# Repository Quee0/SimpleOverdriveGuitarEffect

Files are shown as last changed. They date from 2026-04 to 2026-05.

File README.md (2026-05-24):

# Ignis Overdrive Effect :fire: :guitar:

<p align="left">
  
  
  
  
</p>

<p align="center">
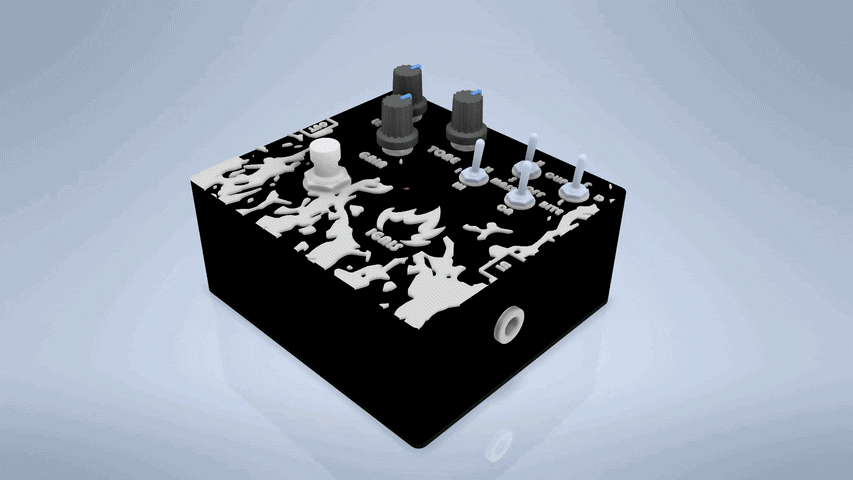
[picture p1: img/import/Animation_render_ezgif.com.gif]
  
</p>

---

## 1. Project overview

### 1.1 General Description

This project presents the complete design and mathematical analysis of a versatile, fully analog overdrive guitar pedal built around an operational amplifier.
At its core, the main amplification block delivers a massive voltage gain (up to 1000x), paired with a flexible multi segmented tonal shaping section. 

> [!NOTE]
>This includes:
>* Hardware pre-amp bass switch to modify the low-end structure before clipping,
>* Low-pass pre-amp filter integrated into the feedback loop, it actively works with gain and can be switched on and off,
>* Customizable clipping: fast-switching silicon diodes and LEDs, hard and soft clipping.
>* Final refinements through a classic passive Tone control (lowpass filter),
>* Master volume stage with DC-blocking (static high pass filter), 

The end result is a highly customizable overdrive capable of spanning from a transparent, mid-focused crunch to a thick, saturated lead tone, demonstrating a practical understanding of circuit design and mathematical theory usage.

### 1.2 Sound Demonstrations

<details>
<summary><b>Soft Clipping, LED Diodes, Mass I, Bite ON, Mid Gain, Low Tone</b></summary>

https://github.com/user-attachments/assets/1be89b33-93ce-4a43-86b3-0c42de0525c9

</details>

<details>
<summary><b>Soft Clipping, LED Diodes, Mass I, Bite ON, Mid Gain, High Tone</b></summary>

https://github.com/user-attachments/assets/2ba2562c-e011-4fdd-8f06-044c0ea2faf1

</details>

<details>
<summary><b>Soft Clipping, LED Diodes, Mass II, Bite ON, Mid Gain, Mid Tone</b></summary>

https://github.com/user-attachments/assets/6c816d3a-e20a-423a-b53f-dbef71fd2bd0

</details>

<details>
<summary><b>Soft Clipping, Fast-switching Diodes, Mass I, Bite ON, Mid Gain, Mid Tone</b></summary>

https://github.com/user-attachments/assets/7a0f3d32-2f00-4b13-9497-afda9a19c826

</details>

<details>
<summary><b>Soft Clipping, Fast-switching Diodes, Mass I, Bite ON, Mid Gain, Mid Tone</b></summary>

https://github.com/user-attachments/assets/31108739-4f4a-404e-89c9-3ae1a5144b9c

</details>

### 1.3 User Guide

* **Footswitch** - `Enable / disable` guitar effect,
* **Level:** Master output volume control.
* **Gain:** Adjusts the voltage amplification of the primary op-amp stage. Turn clockwise to increase the amount of overdrive and saturation.
* **Tone** - Passive high-frequency roll-off. Turn clockwise for a brighter, sharper tone, or counter-clockwise for a darker, warmer sound.
* **Clip** - `Hard / Soft` Clipping mode toggle. *Note: Different clipping modes inherently yield different overall volume and compression levels. You will likely need to compensate with the Level knob.*
* **D** - `Fast-switching / None / LED` choose cliping diodes,
* **Mass** - `II / I / III` choose how massive you want the tone to be, how much to amplify the bass.
* **Bite** - `Off / On` Engages the feedback-loop smoothing capacitor (100pF). Turn it ON to roll off harsh high-end fizz and soften the overall clipping behavior.

---

## 2. Circuit
### 2.1 Schematic Diagram

<p align="center">
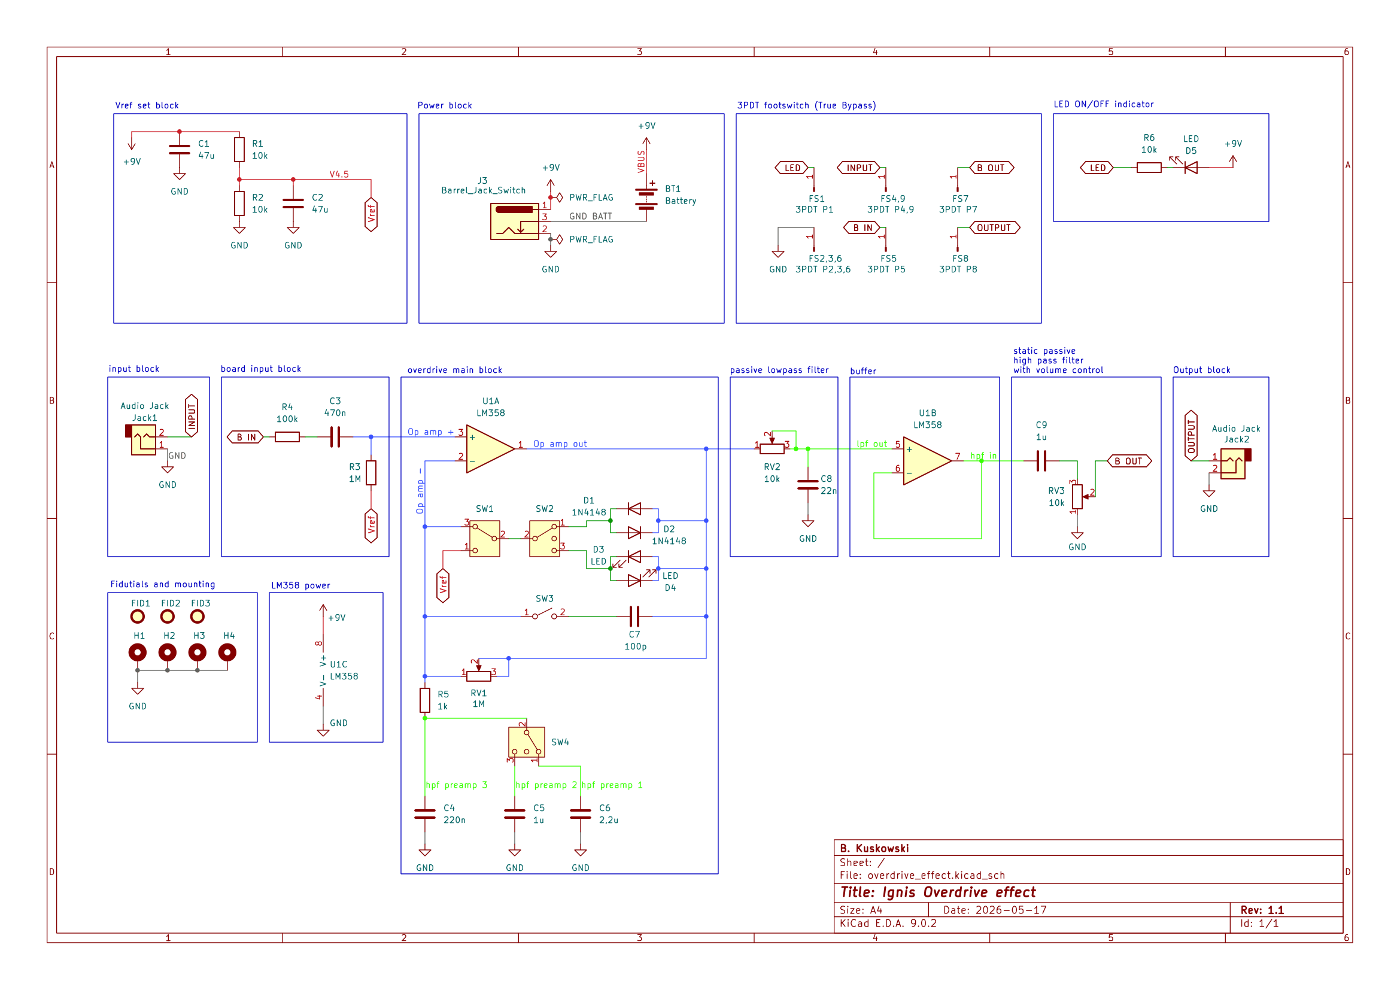
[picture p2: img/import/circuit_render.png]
  
</p>

**Block Diagram Explanation**
* **$V_{ref}$ set block** - steps down the 9V supply to create a 4.5V reference voltage, it allows to add DC part to an AC signal (center between 0V-9V power supply). Capacitors filter out power supply noise and stabilize this reference voltage.
* **Power block** - DC barrel jack integrated with a hardware battery disconnect mechanism. When an external power supply is plugged in, the battery circuit is physically broken to prevent unwanted discharging.
* **3PDT footswitch (True Bypass)** - Footswitch wiring schematic ensuring 100% mechanical true bypass. When the pedal is disengaged, the guitar signal routes directly to the output without passing through any electronic components, preserving maximum tone integrity. It also integrates LED indicators connection to ground when enabled. 
* **LED ON/OFF indicator** - it visually indicates when pedal is enabled.
* **input block and output block** - standard 6.3mm audio jack receiving/sending the instrument signal.
* **board input block** - Coupling capacitor with $V_{ref}$ resistance acts like differenting circuit and blocks DC voltage. Additionally this capacitor loads up to $V_{ref}$ 4.5V voltage that adds DC part to a signal.
* **overdrive main block** - the core of the effect, based on the LM358 operational amplifier. It handles signal amplification based on feedback loop impedances and features a versatile clipping section, offering a choice between fast-switching diodes and LEDs. It also includes tonal modifications: a switchable LPF in the feedback loop (SW3) to smooth out high-end fizz, and a pre-gain HPF (SW4) to control the low-end "mass" entering the clipping stage.
* **passive lowpass filter** - the classic Tone control section.
* **buffer** - effectively separates signal proccesing blocks from influencing one another.
* **static passive high pass filter with volume control** - output coupling capacitor blocks the internal $V_{ref}$ DC part, outputting a pure AC audio signal centered at 0V. Potentiometer acts as a voltage divider providing precise Master Volume control.
* **Fiducials and mounting** - purely mechanical parts to mount and produce PCB.
* **LM358 power** - LM358 powering diagram.

> [!NOTE]
> Upon later revision there are 2 possible further impovements:
> * While setting $V_{ref}$ use buffor to further stabilize reference potential point.
> * Add protective resistance to output of an op amp in main overdrive block.

### 2.2 PCB Layout

<p align="center">
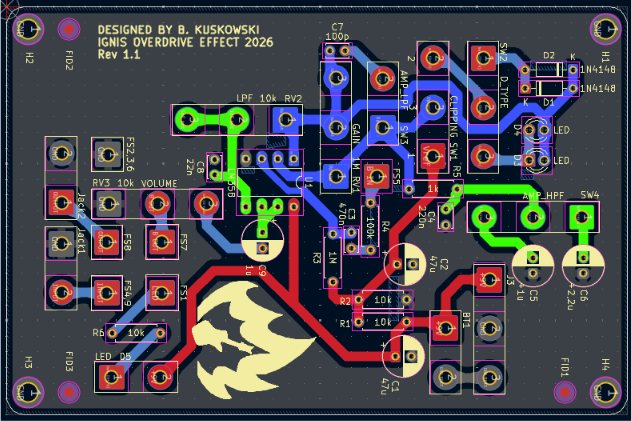
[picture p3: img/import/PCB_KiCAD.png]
  
</p>

<p align="center">
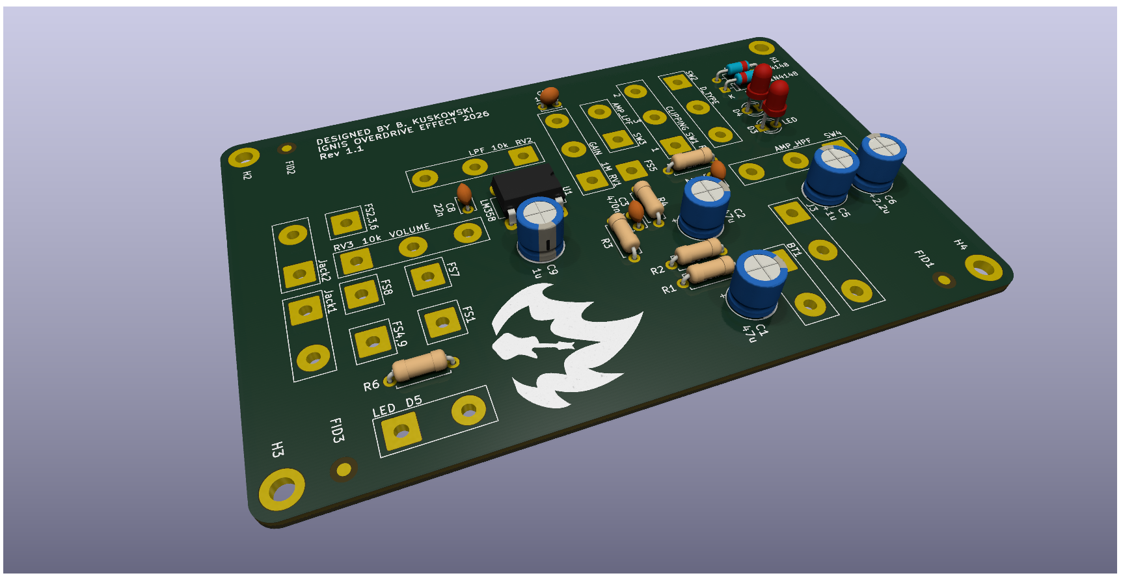
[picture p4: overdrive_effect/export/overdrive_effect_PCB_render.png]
  
</p>

<p align="center">
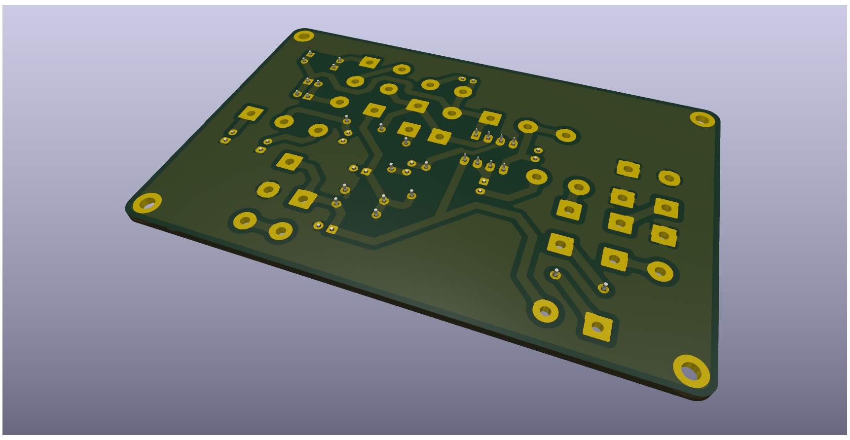
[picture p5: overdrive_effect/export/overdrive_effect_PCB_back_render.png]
  
</p>

PCB Layout Features.
Designed for maximum audio integrity, mechanical reliability, and DIY accessibility:
* **Low Noise (Solid Ground Plane)**: A continuous copper pour acts as an EMI shield, drastically reducing noise.
* **DIY & Fab-Friendly**: Intentionally routed as a single-sided board with wide traces and generous clearances. This makes it perfect for both home DIY etching (using thermotransfer) and professional, automated manufacturing.
* **Easy wiring**: Silkscreen layer was carefully described to assure smooth assembly.
* **Appropriate wire holes**: Apertures are wide enough for diverse wire usage.

<p align="center">
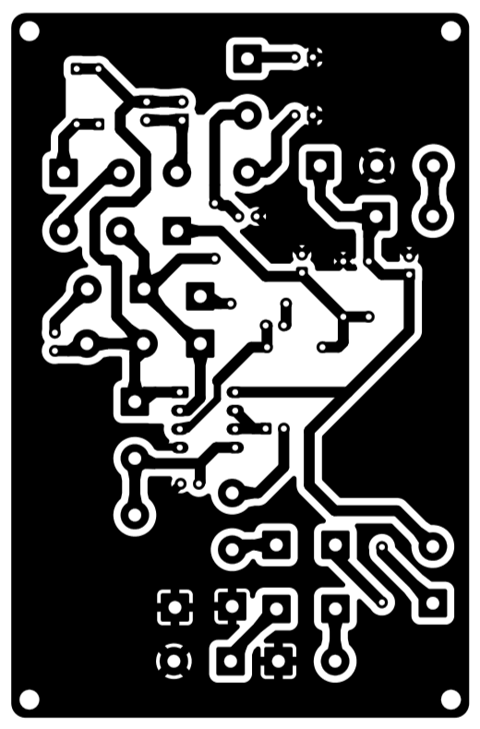
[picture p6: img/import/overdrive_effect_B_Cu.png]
  
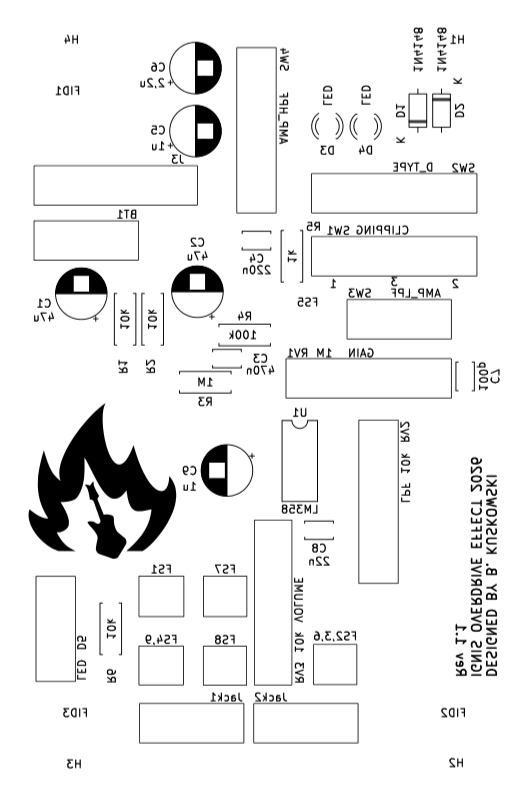
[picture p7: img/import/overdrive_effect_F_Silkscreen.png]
  
</p>

<p align="center">
PNGs of files ready to thermotransfer (pdfs in img\import)
</p>

---

## 3. Circuit analysis math derivation
<details>
<summary><b> Expand for further details </b></summary>

### 3.1 Derivation of cutoff frequency of coupling/decoupling capacitor

In this derivation we consider loaded decoupling capacitor which makes lowpass filter (integrating circuit).
The last derived equation in 3.1 is identical for coupling capacitor working with resistance (differentiating circuit), but it is different on laplace's s-domain, and in fourier analysis (phase and magnitude plots).

#### Voltage divider equation:

$$U_{out}=U_{in} \cdot \frac{Z_L}{Z_L+Z_R}$$

$$U_{out}=U_{in} \cdot \frac{\frac{Z_C Z_{Ro}}{Z_C+Z_{Ro}}}{\frac{Z_C Z_{Ro}}{Z_C+Z_{Ro}}+Z_R} = U_{in} \cdot \frac{Z_C Z_{Ro}}{Z_C Z_{Ro}+Z_C Z_{R}+Z_RZ_{Ro}}$$

#### Laplace's s-domain impedances derivation
Definition of Laplace's transform:

$$F(s) = L[f(t)] = \int_{0}^{\infty} f(t) e^{-st} \, dt \Rightarrow L\left[\frac{d^nf(t)}{dt^n}\right] = s^nF(s)$$

considering no initial conditions.

Impedance of resistance $Z_R$: 

$$U=I\cdot R$$
<!-- $$\mathcal{L}\{U\}=\mathcal{L}\{I\cdot R\}$$-->

$$L[U]=R\cdot L[I]$$

$$Z_R(s)=\frac{U(s)}{I(s)}=R$$

Impedance of capacitance $Z_C$:

$$I=C\cdot \frac{dU}{dt}$$

$$L[I]=C\cdot L[U']$$

$$I(s)=C\cdot sU(s)$$

$$Z_C(s)=\frac{U(s)}{I(s)}=\frac{1}{sC}$$

#### Substituting s-domain impedances to voltage divider equation:

$$G(s)=\frac{U_{out}}{U_{in}}=\frac{\frac{R_o}{sC}} {\frac{R_o}{sC}+\frac{R}{sC}+RR_o}=\frac{R_o}{R_o+R+sCRR_o}$$

$$G(s)=\frac{(\frac{R_o}{R_o+R})}{1+s(\frac{CRR_o}{R_o+R})}$$

Then:

**$$\boxed{G(s)=\frac{K}{1+sT}},\qquad   \boxed{K=\frac{R_o}{R_o+R}},\qquad   \boxed{T=\frac{CRR_o}{R_o+R}}$$**

---

#### Amplitude characteristic - Fourier analysis
Complex s-plane argument definition: $s = \sigma+j\omega$. To get amplitude characteristic we need to analyse holomorphic Fourier transform function. To achieve that we need to get rid of real part of s-plane (constant component $e^\sigma$).

$$G(j\omega)=\frac{K}{1+j\omega T}\cdot\frac{1-j\omega T}{1-j\omega T}=\frac{K-j\omega KT}{1+\omega^2 T^2}$$

$$G(j\omega)=\left[\frac{K}{1+\omega^2 T^2}\right] + j\left[\frac{-\omega KT}{1+\omega^2 T^2}\right]$$

<!-- ![](img\desmos_decoupling_Fourier.svg)(https://www.desmos.com/calculator/vwyactze44) -->
$P(\omega)\left[Q(\omega)\right]$ characteristics:
<p align="center">
  Podpis alternatywny
</p>
<p align="center">
    (https://www.desmos.com/calculator/vwyactze44)
</p>
To derive amplitude-frequency function we must analyse mod.

$$|G(j\omega)|=\sqrt{\frac{K^2}{(1+\omega^2 T^2)^2}+\frac{\omega^2 K^2 T^2}{(1+\omega^2 T^2)^2}}=\frac{K}{\sqrt{1+\omega^2 T^2}}$$

Finding -3dB frequency will be done based on magnitude.

$$A=20\cdot \log\left(\frac{K}{\sqrt{1+\omega^2 T^2}}\right)$$

Cutoff condition:

$$A(\omega_{-3dB})=A(0)-3$$

$$20\cdot \log\left(\frac{K}{\sqrt{1+\omega^2 T^2}}\right)=20\cdot \log\left(\frac{K}{\sqrt{1+0^2 T^2}}\right)-3$$

$$10\left[\log\left(\frac{K^2}{(1+\omega^2 T^2)}\right)-\log\left(K^2\right)\right]=-3$$

$$\log\left(\frac{1}{(1+\omega^2 T^2)}\right)=-0,3$$

$$\frac{1}{(1+4\pi^2f^2 T^2)}=10^{-0,3}$$

$$10^{-0,3}+10^{-0,3}4\pi^2f^2 T^2=1$$

$$f=\sqrt{\frac{\frac{10^{-0,3}}{1-10^{-0,3}}}{4\pi^2T^2}} \approx \frac{1}{2\pi T}$$

Substitute T:

$$f=\frac{R_o+R}{2\pi CRR_o}=\frac{R}{2\pi CRR_o}+\frac{R_o}{2\pi CRR_o}$$

**$$\boxed{f=\frac{1}{2\pi RC}+\frac{1}{2\pi R_oC}}$$**

---

### 3.2 Derivation of voltage divider resistance values

We consider loaded symetric voltage divider

#### Impedance

$$R_{eq1}=\frac{RR_o}{R+R_o}$$

$$\lim_{R_o \to \infty} R_{eq1}= \lim_{R_o \to \infty}\frac{R}{\frac{R}{R_o}+1}=R$$

$$R_{eq}=2\cdot R$$

#### Flowing current loss

$$I=\frac{V_{cc}}{R_{eq}}=\frac{V_{cc}}{2R}$$

#### Thevenin's resistance

$$R_{TH}=\frac{RR}{R+R}=\frac{R}{2} \Rightarrow R = 2\cdot R_{TH}$$

#### Current loss vs Thevenin's resistance

Substituting both equations:

**$$\boxed {I(R_{TH})=\frac{V_{cc}}{4\cdot R_{TH}}}$$**

Ideal voltage source should have $R_{TH} \to 0$, to be as stable as possible. Ideal current loss should be $I \to 0$. Graphing this function allow to pick optimal resistance values.

$I(R_{TH})$  with $V_{cc}=9V$ characteristics:
<p align="center">
  Podpis alternatywny
</p>
<p align="center">
    (https://www.desmos.com/calculator/zl9quwhx7r)
</p>

---

### 3.3 Derivation of pullup resistor value

Considering methodology of choosing pullup resistors, low potential on signal line should not draw much current.
On the other hand, operational amplifier has its bias current which will be drawn no matter what. It limits upper value of resistance, voltage drop on this resistor should not affect effect.

In project LM358 was used, so its bias current is around $45 nA = 45\cdot 10^{-9} A$

$$U = I\cdot R$$

$$R = \frac{U_{loss}}{45\cdot 10^{-9}}$$

Characteristics:
<p align="center">
  Podpis alternatywny
</p>
<p align="center">
    (https://www.desmos.com/calculator/fuyu1ywsum)
</p>

---

### 3.4 Operational amplifiers

Op amps has very high input impedance ($Z_{in} \to \infty$) and very low output impedance ($Z_{out} \to 0$).
They can be analysed using 2 rules:
1. Op amps try to sustain same potential on both of its inputs,
2. Op amps bias current is negligible small (often $I \to 0$).

---

Using 2 rules, non-inverting amp can be modeled with:

$$U_{in} = U_{+} = U_{-} = Z_1 \cdot I$$

$$U_{out} = U_{Z_1} + U_{Z_2} = I\cdot Z_1 + I\cdot Z_2 \Rightarrow I = \frac{U_{out}}{Z_1 + Z_2}$$

$$G(s) = \frac{Z_2 (s)}{Z_1(s)} + 1$$

In this effect we are enabling user to regulate $Z_2$ (diode type, potentiometer and capacitor). We use capacitor $C_4$ to limit gain for DC current.
Considering only $1M\Omega$ potentiometer and using information derived in 3.1:

$$G(s) = \frac{R_{V1}}{R_5+ \frac{1}{sC_4}} + 1 = \frac{sR_{V1} C_4}{sR_5 C_4 + 1} + 1 = \frac{1 + sC_4(R_{V1} + R_5)}{1 + sR_5C_4}$$

To calculate gain in somewhat same way that we derived 3.1 $s = j\omega$ :

$$G(j\omega) = \frac{1 + j\omega C_4(R_{V1} + R_5)}{1 + j\omega R_5C_4} = [\frac{1+\omega^2 C_4^2 R_5 (R_{V1}+R_5)}{1+\omega^2 R_5^2 C_4^2}] + j [\frac{\omega C_4 R_{V1}}{1+\omega^2 R_5^2 C_4^2}]$$

$$|G(j\omega)| = \sqrt{Re[G(j\omega)]^2+Im[G(j\omega)]^2} = \sqrt{\frac{1 + \omega^2 C_4^2(R_{V1} + R_5)^2}{1 + \omega^2 R_5^2 C_4^2}}$$

So impedance for DC current is:

$$\lim_{\omega \to 0} |G(j\omega)| = 1$$

So impedance for high frequency AC current is:

$$\lim_{\omega \to \infty} |G(j\omega)| = \frac{R_{V1}}{R_5} + 1$$

</details>

---

## 4. Element selection

<details>
<summary><b>Expand for further details</b></summary>

### 4.1 Voltage divider

Using $I(R_{TH})=\frac{V_{cc}}{4\cdot R_{TH}}\qquad$ (3.2).
Voltage divider should not drain more than $0.5 mA$, so:

$$0.5 \cdot 10^{-3} > \frac{9}{4\cdot R_{TH}}$$

$$2 \cdot 10^{-3} \cdot R_{TH} > 9$$

$$R_{TH} > 4,5 \cdot 10^3 \Rightarrow R_{1,2} > 9 k\Omega$$

**$$\boxed{R_{1,2} = 10 k\Omega}$$**

### 4.2 Pullup resistor

Using $R = \frac{U_{loss}}{45\cdot 10^{-9}}$ (3.4).
Maximal acceptable voltage drop is around $0.05 V$, so:

$$R_3 = \frac{0,05}{45\cdot 10^{-9}} \approx 1,111 \cdot 10^6 \Omega \approx 1 M\Omega$$

**$$\boxed{R_3 = 1M\Omega}$$**

### 4.3 Input resistor

It is standard current and voltage limiting resistor.

**$$\boxed{R_4 = 100k\Omega}$$**

### 4.4 Filtering, gain and volume potentiometers

Potentiometers were chosen based on availability and functionality.
Picking $10k\Omega$ potentiometers grants optimal selection of coupling and decoupling capacitors to work with (look 4.5). Also in main feedback loop there is main bass level control, so not to do too many knobs we stuck to a static highpass filter. It also works with $10k\Omega$ potentiometer as volume control. it gives relatively low internal resistance of an effect.

**$$\boxed{R_{V2,V3} = 10k\Omega}$$**

Gain potentiometer was also chosen based on construction standards, but to make effect more customizable we chose $1M\Omega$ which grants more boost.

**$$\boxed{R_{V1} = 1M\Omega}$$**

### 4.5 Coupling/decoupling capacitors

Decoupling $9V$ source and $4.5V$($V_{ref}$) after voltage divider is done by $C_1$ and $C_2$. Values were chosen using Thevenin's method.

Capacitor $C_2$ works with $5 k\Omega$ resistance, we want to cutoff frequencies all above $0.01 Hz$:

$$R_{TH} = \frac{10k \cdot 10k}{10k + 10k} = 5k\Omega$$

$$C_2 > \frac{1}{2\pi R_{TH} f} = \frac{1}{2\pi 5000 \cdot 0,01} \Rightarrow C_2 > 3,18 \mu F$$

**$$\boxed{C_2 = 47 \mu F}$$**

Based on that selection to unify values and stick with industry standards $C_1$ is also $47 \mu F$. 
It will work effectively with power supply and battery to supress instant voltage spikes.

---

Capacitor $C_3$ works with $>1M\Omega$ of resistance as highpass filter to block any DC current into amplification circuit. 
We can pass everything above $0,3 Hz$:

$$C_3 = \frac{1}{2\pi Rf} = \frac{1}{2\pi 10^6 \cdot 0,3} = 531 \cdot 10^{-9}$$

**$$\boxed{C_3 = 470 nF}$$**

---

Post amplification passive filtering is done by two segments.

Using buffer allows to separate 2 filters. Load resistance in approximation infinitely small. Derived equation looks like this (3.1):

$$\lim_{R_o \to \infty} f= \lim_{R_o \to \infty} \frac{1}{2\pi RC}+\frac{1}{2\pi R_oC} = \frac{1}{2\pi RC}+\frac{1}{2\pi \infty C} = \frac{1}{2\pi RC}$$

We want low pass filte maximal cutoff point to be 5 kHz:

$$5000 = \frac{1}{2\pi \cdot 10000 \cdot C }\Rightarrow C = \frac{1}{2\pi \cdot 10000 \cdot 5000} \approx 3,18 \cdot 10^{-9} F$$

**$$\boxed{C_8 = 3,3 nF}$$**

We want high pass filter cutoff point to be 15.9Hz (it will be fixed, look 4.4):

$$60 = \frac{1}{2\pi \cdot 10000 \cdot C }\Rightarrow C = \frac{1}{2\pi \cdot 10000 \cdot 10} \approx 3,18 \cdot 10^{-6}$$

**$$\boxed{C_9 = 1 \mu F}$$**

### 4.6 Active buffer

Buffer takes advantage of impedance characteristics of op amp. Using rule 1 we can derive:

$$U_{-in} = U_{+in} = U_{out}$$

Voltage on the output is the same as the voltage on the input. Buffer separates audio pipeline.

### 4.7 Main op amp feedback loop

To give wide range of gain we picked $R_{V1} = 1 M\Omega$, for $1000x$ voltage boost we need to calculate $R_5$ value:

$$R = \frac{R_{V1}}{k+1} = \frac{1 M\Omega}{1000+1} \approx 999 \Omega$$

**$$\boxed{R_5 = 1k\Omega}$$**

---

Based on this selection we choose $C_4$ value (using derivation from 3.1). Value of this capacitor controls the filtering before amplification. On guitar it can be described as pre amp bass control. To further customize the effect aditional switch was added. It has 3 possible cutoff frequencies. We chose typical values used in overdrives:

**$$\boxed{C_4 = 220n, C_5 = 1\mu F, C_6 = 2,2 \mu F}$$**

So based on chosen capacitance:

$$f_4 = \frac{1}{2\pi R_5 C_4} \approx 723 Hz$$

$$f_5 = \frac{1}{2\pi R_5 C_5} \approx 159 Hz$$

$$f_6 = \frac{1}{2\pi R_5 C_6} \approx 72,3 Hz$$

---

Additionally we added switch (SW3) to allow user to join capacitor $C_7$ to soften diodes behaviour.
It modifies $Z_2$ value:

$$Z_2 = \frac{R_{V1} \cdot \frac{1}{sC_7}}{R_{V1} + \frac{1}{sC_7}} = \frac{R_{V1}}{sR_{V1} C_7 + 1}$$

So again value was chosen based on standard.

**$$\boxed{C_7 = 100 pF}$$**

---

Effect has 2 pair of diodes to choose from:

* LEDs
* Fast switching diodes

They can be enabled in soft clipping mode (in feedback loop), and in hardclipping (disconnected from loop, shortened to ground).

</details>

## 5. 3D Printed Enclosure & Mechanicals

<p align="center">
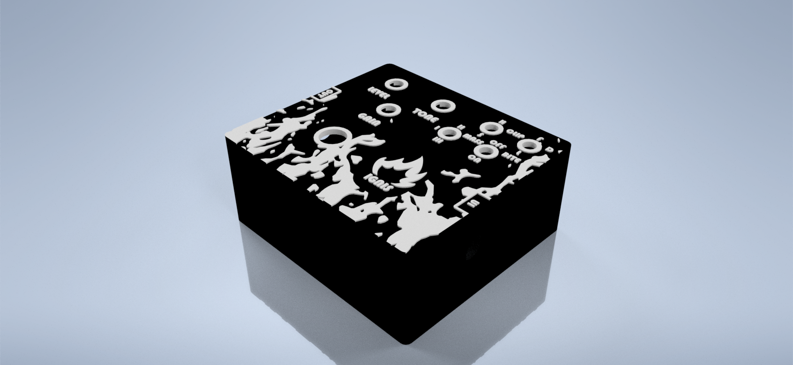
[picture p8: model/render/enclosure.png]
  
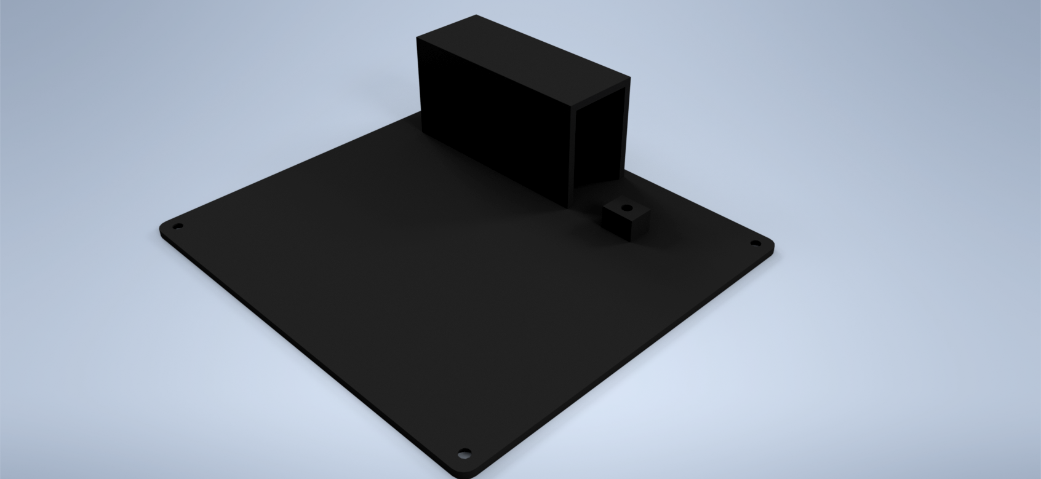
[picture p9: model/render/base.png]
  
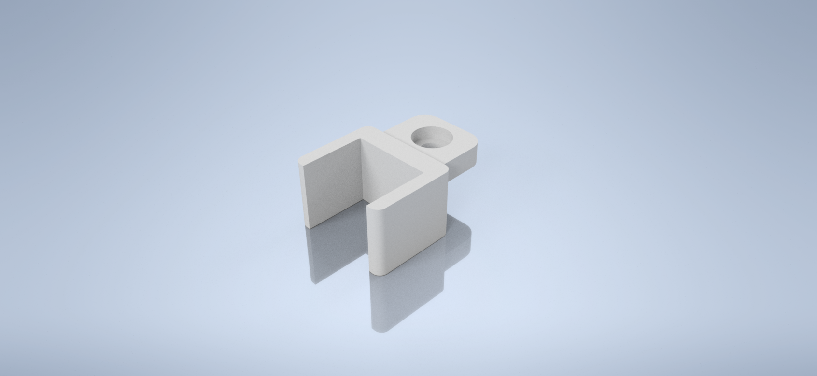
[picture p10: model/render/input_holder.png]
  
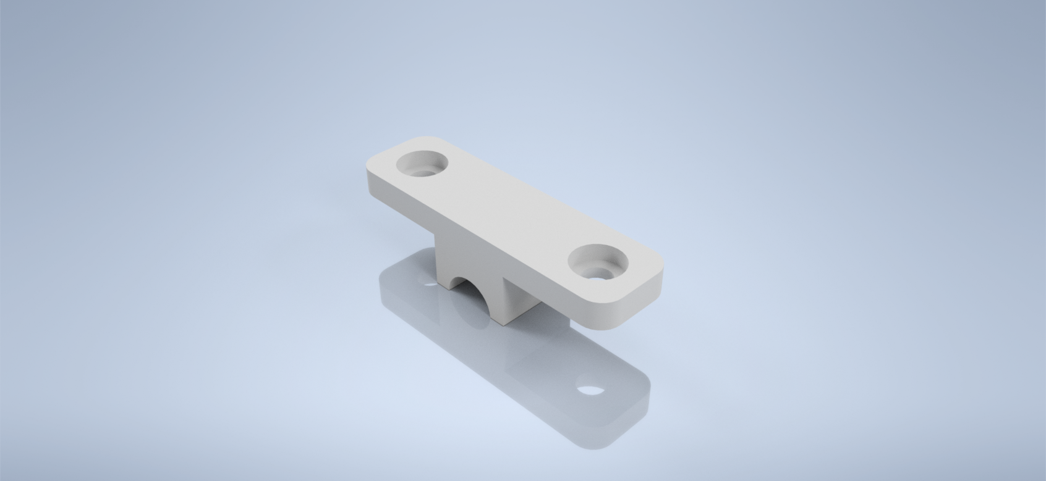
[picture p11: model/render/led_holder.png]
  
</p>

The project includes custom `.stl` files for a fully 3D-printable enclosure, designed from the ground up for mechanical reliability and easy assembly.
* **Rigid Construction** - engineered for high structural stability. The enclosure easily withstands the mechanical stress of heavy footswitch stomping without flexing or bending.
* **Modular Sub-Mounts** - features dedicated, small printable mounts for the LED indicator and DC power jack. Instead of painfully gluing these parts deep inside the main body, you can comfortably secure them to their sub-mounts first, making final assembly and future maintenance incredibly modular.
* **Durable Fastening** - the design utilizes M2 heat-set threaded inserts, providing strong, reusable machine-screw connections for the backplate instead of easily stripped plastic threads.
* **Accessible Dual-Color Graphics** - the front panel design allows for a professional, two-color aesthetic without the need for an AMS (Automatic Material System). The graphics are printed at a specific height, allowing you to achieve the dual-color look simply by pausing the print and manually swapping the filament.

## 6. Bill of materials

| Reference | Qty | Value | Description/Type |
| --- | --- | --- | --- |
| BT1 | 1 | Battery connector  | Female 6F22 connector |
| C1,C2 | 2 | 47u | Electrolytic Capacitor THT 9V (Radial) |
| C3 | 1 | 470n | Ceramic/Electrolytic Capacitor THT 9V |
| C4 | 1 | 220n | Ceramic Capacitor THT 9V |
| C5,C9 | 2 | 1u | Electrolytic Capacitor THT 9V (Radial) |
| C6 | 1 | 2.2u | Electrolytic Capacitor THT 9V (Radial) |
| C7 | 1 | 100p | Ceramic Capacitor THT 9V |
| C8 | 1 | 22n | Ceramic Capacitor THT 9V |
| D1,D2 | 2 | 1N4148 | 1N4148 500mV |
| D3,D4 | 2 | LED | Red LED THT D3.0mm |
| D5 | 1 | LED | Red LED THT D5.0mm |
| FS1-9 | 1 | 3PDT | 3PDT Bistable Footswitch M12 |
| J3 | 1 | Barrel_Jack_Switch | Standard 5.5 mm x 2.1 mm female DC supply connector |
| Jack1,Jack2 | 2 | Audio Jack | Female barrel jack 6.35mm - Thomann SK096\* |
| R1,R2,R6 | 3 | 10k | Standard THT (1/4W) |
| R3 | 1 | 1M | Standard THT (1/4W) |
| R4 | 1 | 100k | Standard THT (1/4W) |
| R5 | 1 | 1k | Standard THT (1/4W) |
| RV1 | 1 | 1M | Standard 16mm Rotary Potentiometer (with M7 Nut) |
| RV2,RV3 | 2 | 10k | Standard 16mm Rotary Potentiometer (with M7 Nut) |
| Knob | 3 | \- | 15x17mm Plastic Knob |
| SW1, SW3 | 2 | \- | MTS 102 (with M6 Nut) |
| SW2, SW4 | 2 | \- | MTS 103 (with M6 Nut) |
| U1 | 1 | LM358 | Standard DIP-8 |
| PCB | 1 | \- | Professionally or DIY manufactured (files) |
| enclosure | 1 | \- | 3D PETG Print bicolor (files) |
| base | 1 | \- | 3D PETG Print monocolor (files) |
| LED holder | 1 | \- | 3D PETG Print monocolor (files) |
| M2 insert | 9 | \- | M2x4mm |
| M2 screw | 9 | \- | M2x6mm |
| wire | \>5.5m | \- | AWG 22 |
| heatshrink | 60cm | \- | <2mm |
| WAGO connector | 2 | \- | WAGO 221-412\* |

*- it can be easily replaced by similar element

> [!NOTE]
> Note: The total estimated cost of manufacturing this project (including all electronic components, PCB fabrication, and 3D printing materials) is around `$28` / `€24`, offering boutique-level versatility at a fraction of the retail price.

## 7. Assembly Notes

1. Prepare all necessary components, 3D print the enclosure files (.stl), and fabricate the PCB (e.g., using the DIY toner transfer method) or order it from a manufacturer.
2. Solder all through-hole components onto the PCB.
3. Solder all connection wires to the board pads. A wire length of 12-13 cm is fully sufficient for routing.
4. Solder wires to the toggle switches and potentiometers, securing all solder joints with heat shrink tubing.
5. Pay close attention to the pin numbering on the silkscreen. Pins are numbered from 1 to 3 starting from the side with the printed text. Note that there is one clearly labeled exception to this rule.
6. Solder the designated wires to the audio input and output jacks.
7. Using a soldering iron, melt the 9 threaded inserts (M2) into their designated holes in the 3D-printed enclosure parts.
8. Insert the potentiometers and switches through the front panel and screw them securely in place.
9. Mount the audio jacks through the enclosure walls and connect their wires to the main board using WAGO connectors, it allows easy disasemblly.
10. Glue the status LED and the DC power jack into their dedicated 3D-printed holders.
11. Screw the assembled LED holder, the main PCB, and the DC jack holder into the enclosure while carefully guiding wires.
12. Screw on the bottom base plate to close the enclosure and complete the assembly. *You can optionaly add adhesive rubber pads*

<details>
<summary><b>DIY production photos</b></summary>

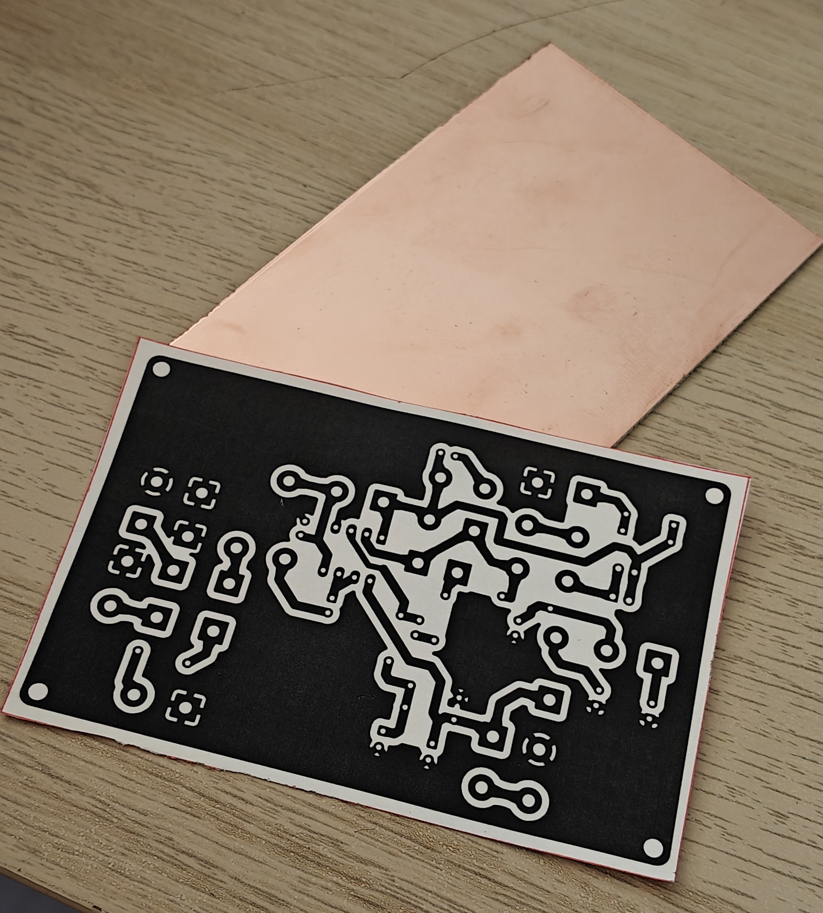
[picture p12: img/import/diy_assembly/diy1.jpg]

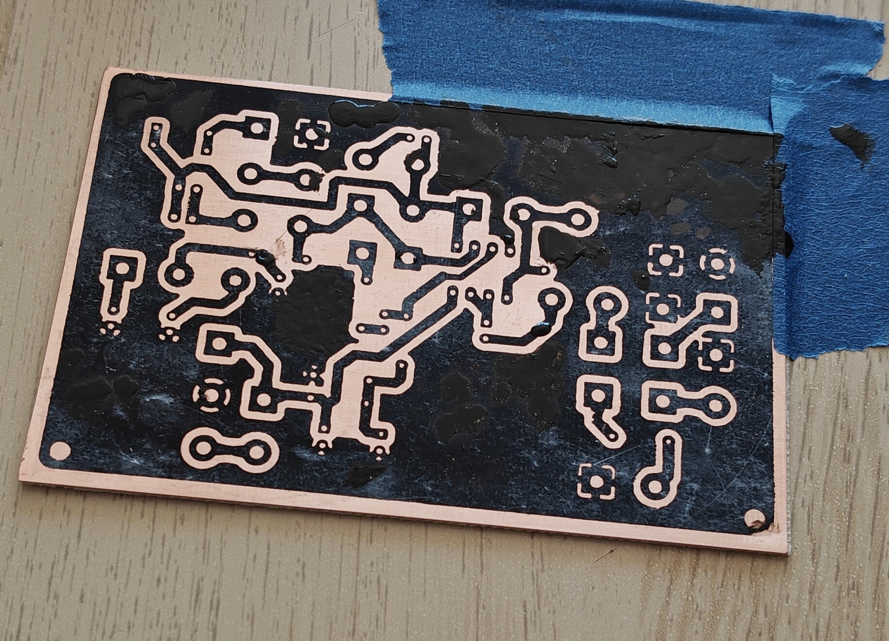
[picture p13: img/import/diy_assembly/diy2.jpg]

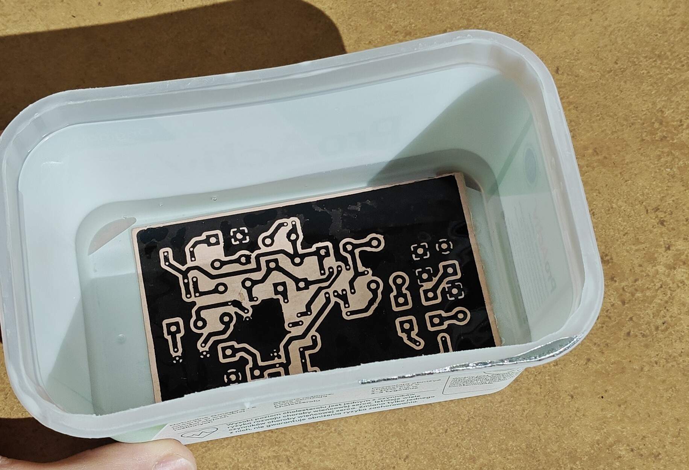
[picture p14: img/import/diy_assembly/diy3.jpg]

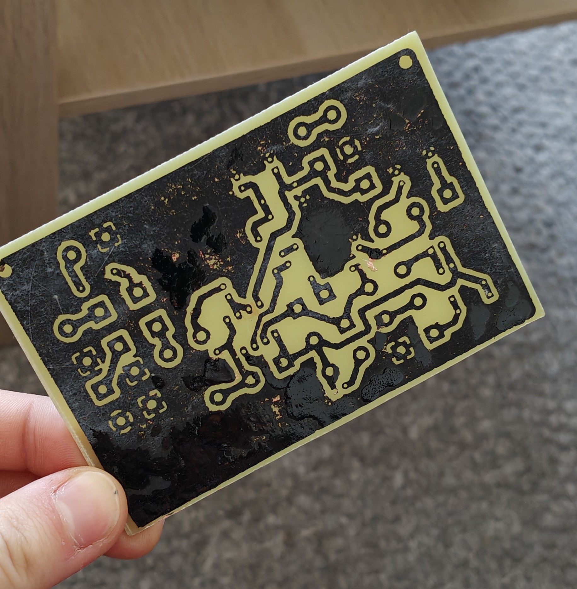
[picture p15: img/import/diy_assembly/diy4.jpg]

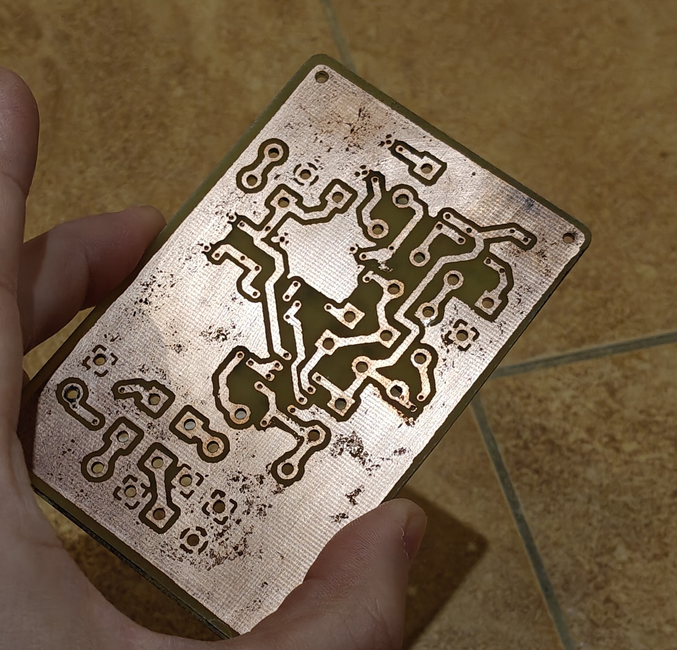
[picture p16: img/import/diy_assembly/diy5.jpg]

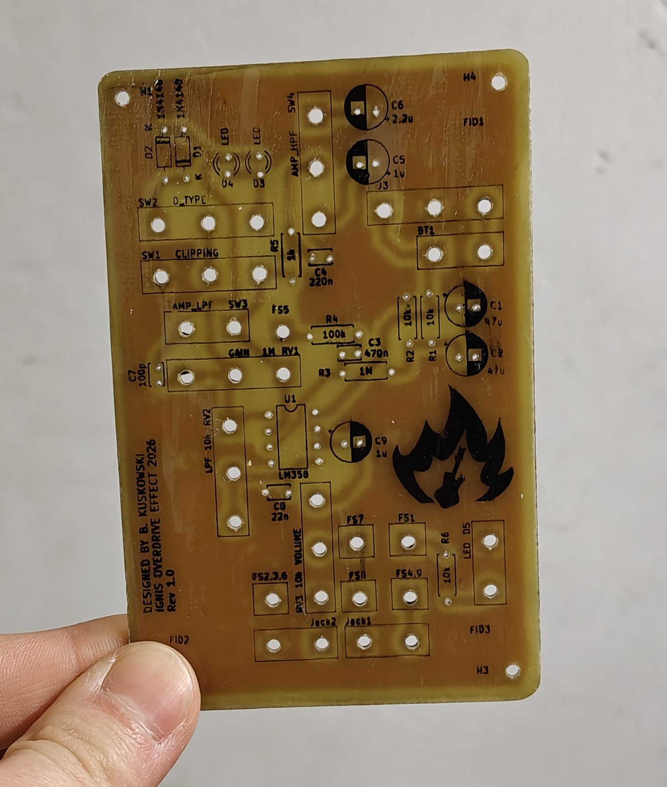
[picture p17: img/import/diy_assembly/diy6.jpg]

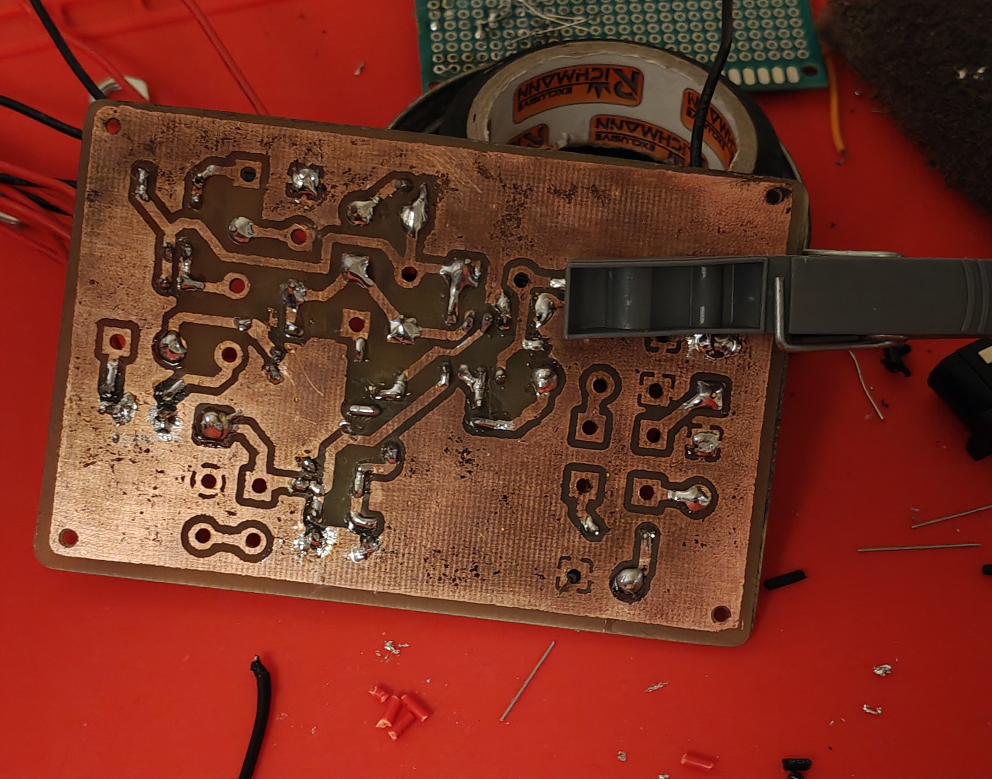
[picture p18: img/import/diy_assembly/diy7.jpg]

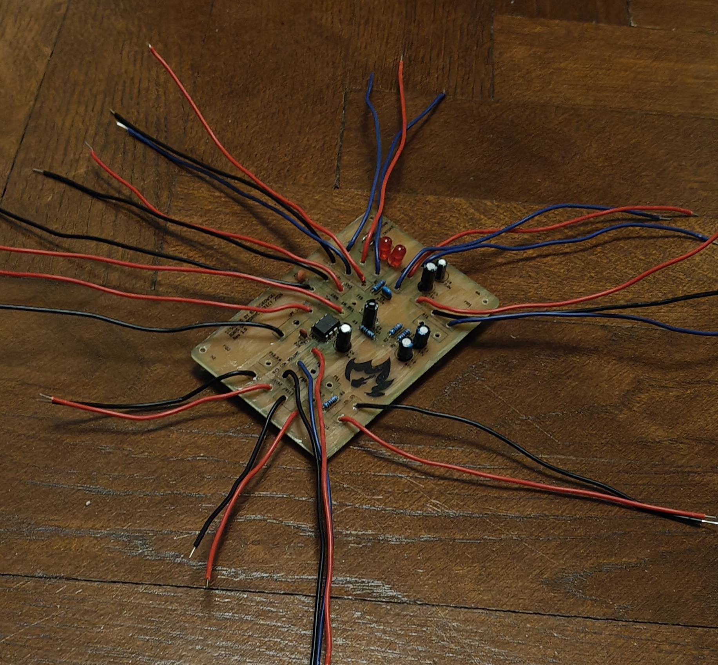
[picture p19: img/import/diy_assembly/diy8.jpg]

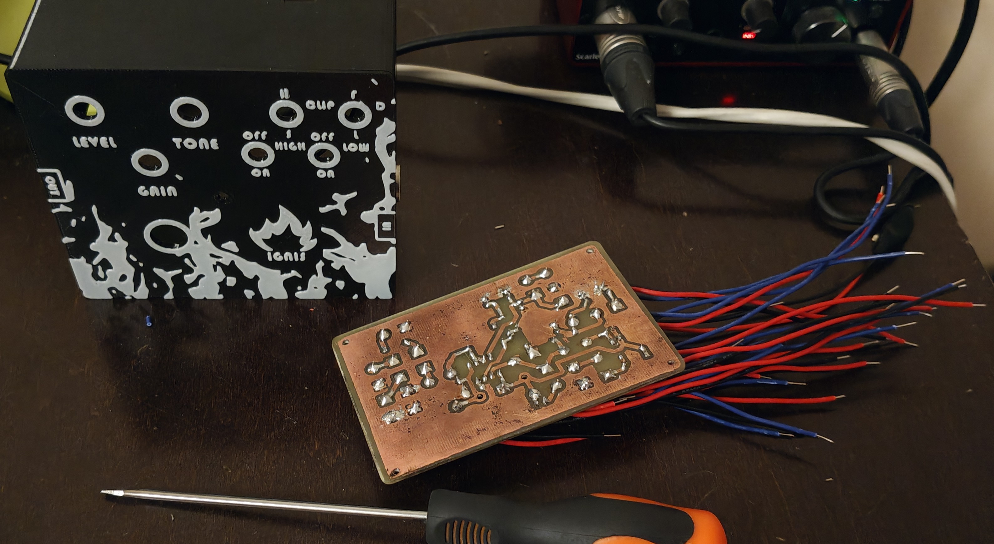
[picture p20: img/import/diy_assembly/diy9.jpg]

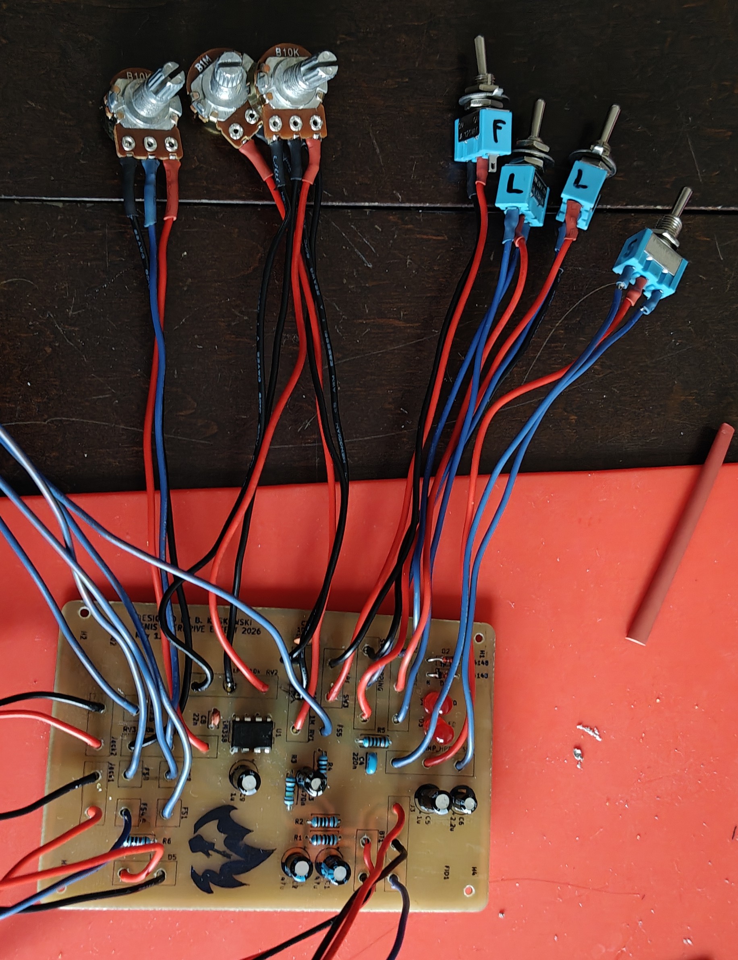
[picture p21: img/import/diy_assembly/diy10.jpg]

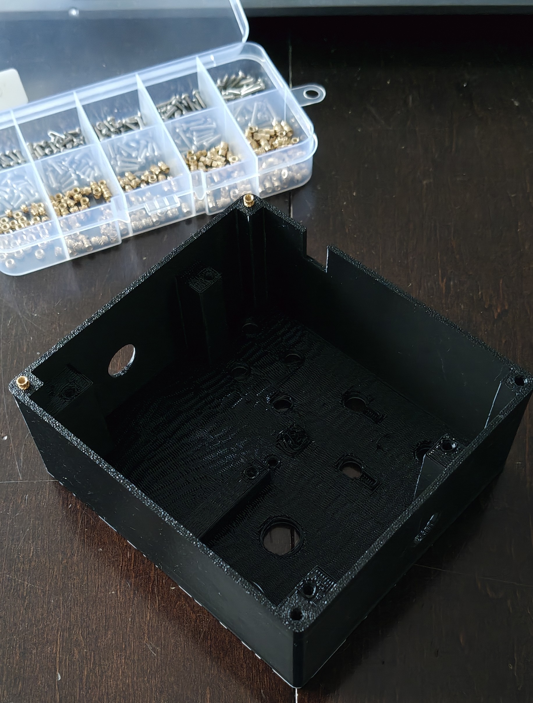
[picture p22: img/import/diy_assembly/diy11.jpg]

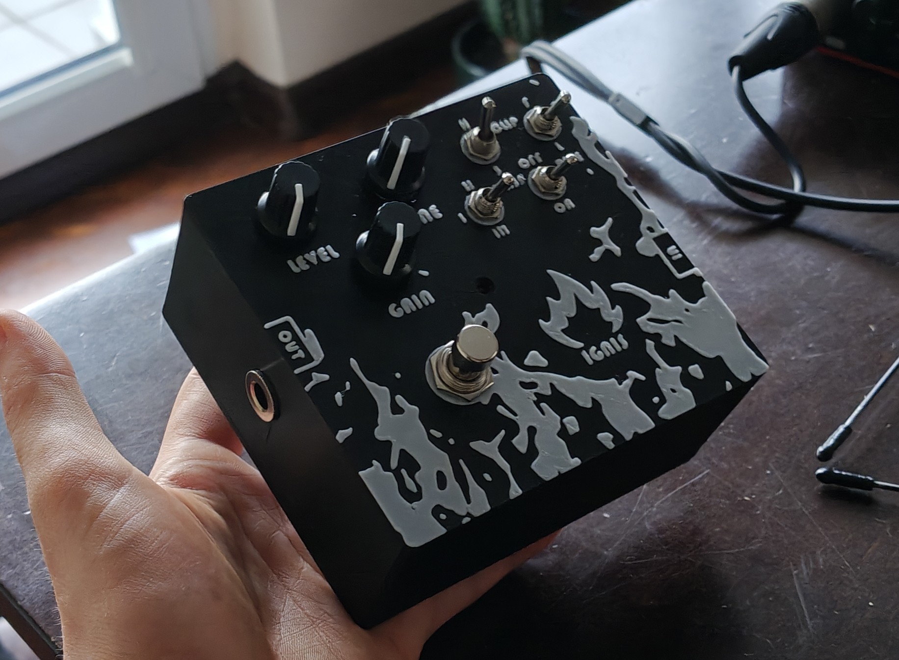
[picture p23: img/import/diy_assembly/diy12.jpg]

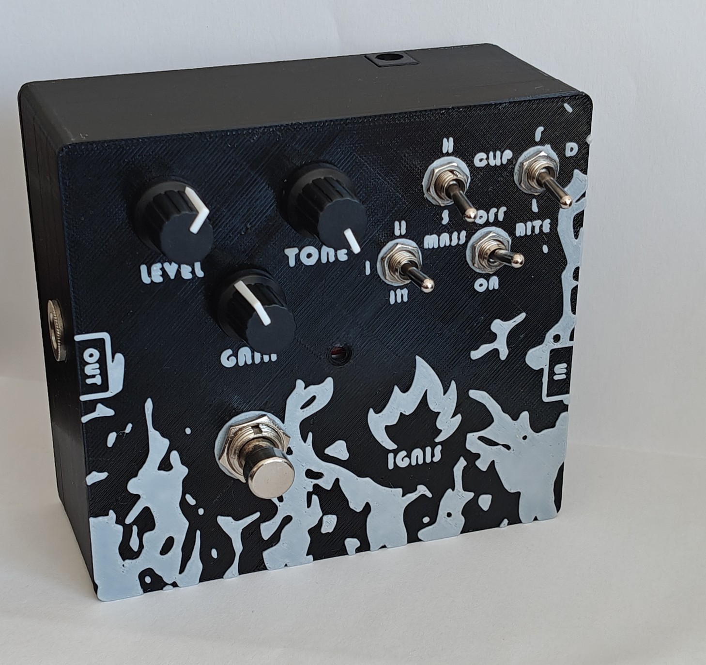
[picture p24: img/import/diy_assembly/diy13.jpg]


</details>

## 8. License

Shield: [][cc-by-nc]

This work is licensed under a
[Creative Commons Attribution-NonCommercial 4.0 International License][cc-by-nc].

[][cc-by-nc]

[cc-by-nc]: https://creativecommons.org/licenses/by-nc/4.0/
[cc-by-nc-image]: https://licensebuttons.net/l/by-nc/4.0/88x31.png
[cc-by-nc-shield]: https://img.shields.io/badge/License-CC%20BY--NC%204.0-lightgrey.svg

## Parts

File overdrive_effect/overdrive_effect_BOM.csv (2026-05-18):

Reference | Qty | Value | DNP | Exclude from BOM | Exclude from Board | Footprint | Datasheet
BT1 | 1 | Battery |  |  |  | Connector_Wire:SolderWire-1sqmm_1x02_P7.8mm_D1.4mm_OD3.9mm | ~
C1,C2 | 2 | 47u |  |  |  | Capacitor_THT:CP_Radial_D6.3mm_P2.50mm | ~
C3 | 1 | 470n |  |  |  | Capacitor_THT:C_Disc_D3.4mm_W2.1mm_P2.50mm | ~
C4 | 1 | 220n |  |  |  | Capacitor_THT:C_Disc_D3.4mm_W2.1mm_P2.50mm | ~
C5,C9 | 2 | 1u |  |  |  | Capacitor_THT:CP_Radial_D6.3mm_P2.50mm | ~
C6 | 1 | 2,2u |  |  |  | Capacitor_THT:CP_Radial_D6.3mm_P2.50mm | ~
C7 | 1 | 100p |  |  |  | Capacitor_THT:C_Disc_D3.4mm_W2.1mm_P2.50mm | ~
C8 | 1 | 22n |  |  |  | Capacitor_THT:C_Disc_D3.4mm_W2.1mm_P2.50mm | ~
D1,D2 | 2 | 1N4148 |  |  |  | Diode_THT:D_DO-35_SOD27_P7.62mm_Horizontal | https://assets.nexperia.com/documents/data-sheet/1N4148_1N4448.pdf
D3,D4 | 2 | LED |  |  |  | LED_THT:LED_D3.0mm | ~
D5 | 1 | LED |  |  |  | Connector_Wire:SolderWire-1sqmm_1x02_P7.8mm_D1.4mm_OD3.9mm | ~
FID1,FID2,FID3 | 3 | Fiducial |  | Wyklucz z BOM |  | Fiducial:Fiducial_1.5mm_Mask3mm | ~
FS1 | 1 | 3PDT P1 |  |  |  | Connector_Wire:SolderWire-1sqmm_1x01_D1.4mm_OD3.9mm | ~
FS2,3,6 | 1 | 3PDT P2,3,6 |  |  |  | Connector_Wire:SolderWire-1sqmm_1x01_D1.4mm_OD3.9mm | ~
FS4,9 | 1 | 3PDT P4,9 |  |  |  | Connector_Wire:SolderWire-1sqmm_1x01_D1.4mm_OD3.9mm | ~
FS5 | 1 | 3PDT P5 |  |  |  | Connector_Wire:SolderWire-1sqmm_1x01_D1.4mm_OD3.9mm | ~
FS7 | 1 | 3PDT P7 |  |  |  | Connector_Wire:SolderWire-1sqmm_1x01_D1.4mm_OD3.9mm | ~
FS8 | 1 | 3PDT P8 |  |  |  | Connector_Wire:SolderWire-1sqmm_1x01_D1.4mm_OD3.9mm | ~
H1,H2,H3,H4 | 4 | MountingHole_Pad |  | Wyklucz z BOM |  | MountingHole:MountingHole_2.7mm_M2.5_DIN965_Pad | ~
J3 | 1 | Barrel_Jack_Switch |  |  |  | Connector_Wire:SolderWire-1sqmm_1x03_P7.8mm_D1.4mm_OD3.9mm | ~
Jack1,Jack2 | 2 | Audio Jack |  |  |  | Connector_Wire:SolderWire-1sqmm_1x02_P7.8mm_D1.4mm_OD3.9mm | ~
R1,R2,R6 | 3 | 10k |  |  |  | Resistor_THT:R_Axial_DIN0207_L6.3mm_D2.5mm_P7.62mm_Horizontal | ~
R3 | 1 | 1M |  |  |  | Resistor_THT:R_Axial_DIN0207_L6.3mm_D2.5mm_P7.62mm_Horizontal | ~
R4 | 1 | 100k |  |  |  | Resistor_THT:R_Axial_DIN0207_L6.3mm_D2.5mm_P7.62mm_Horizontal | ~
R5 | 1 | 1k |  |  |  | Resistor_THT:R_Axial_DIN0207_L6.3mm_D2.5mm_P7.62mm_Horizontal | ~
RV1 | 1 | 1M |  |  |  | Connector_Wire:SolderWire-1sqmm_1x03_P7.8mm_D1.4mm_OD3.9mm | ~
RV2,RV3 | 2 | 10k |  |  |  | Connector_Wire:SolderWire-1sqmm_1x03_P7.8mm_D1.4mm_OD3.9mm | ~
SW1 | 1 | SW_Nidec_CAS-120A1 |  |  |  | Connector_Wire:SolderWire-1sqmm_1x03_P7.8mm_D1.4mm_OD3.9mm | https://www.nidec-components.com/e/catalog/switch/cas.pdf
SW2,SW4 | 2 | SW_SPDT_MSM |  |  |  | Connector_Wire:SolderWire-1sqmm_1x03_P7.8mm_D1.4mm_OD3.9mm | ~
SW3 | 1 | SW_SPST |  |  |  | Connector_Wire:SolderWire-1sqmm_1x02_P7.8mm_D1.4mm_OD3.9mm | ~
U1 | 1 | LM358 |  |  |  | Package_DIP:DIP-8_W7.62mm_LongPads | http://www.ti.com/lit/ds/symlink/lm2904-n.pdf

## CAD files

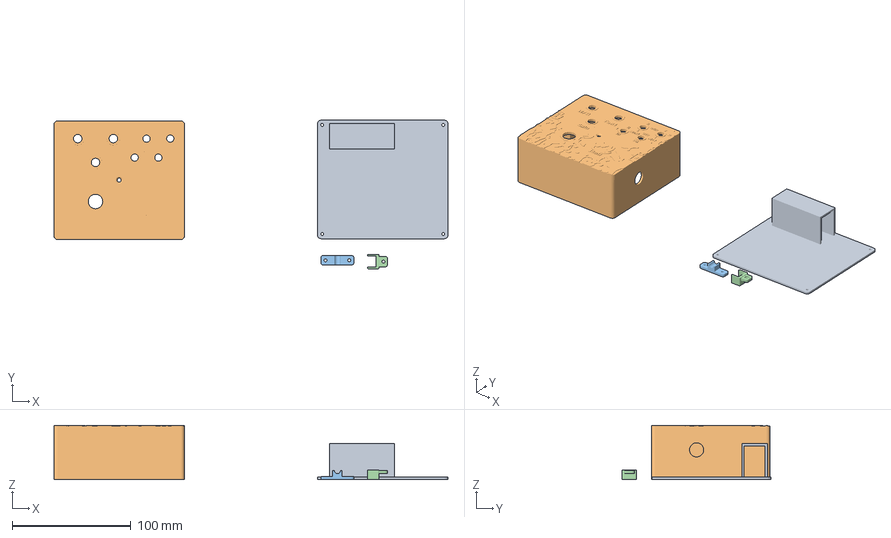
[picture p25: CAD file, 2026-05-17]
model/export/overdrive_slicer_model.3mf
332.1 x 125.4 x 45.6 mm
base.stl
enclosure.stl
led_holder.stl
input_holder.stl

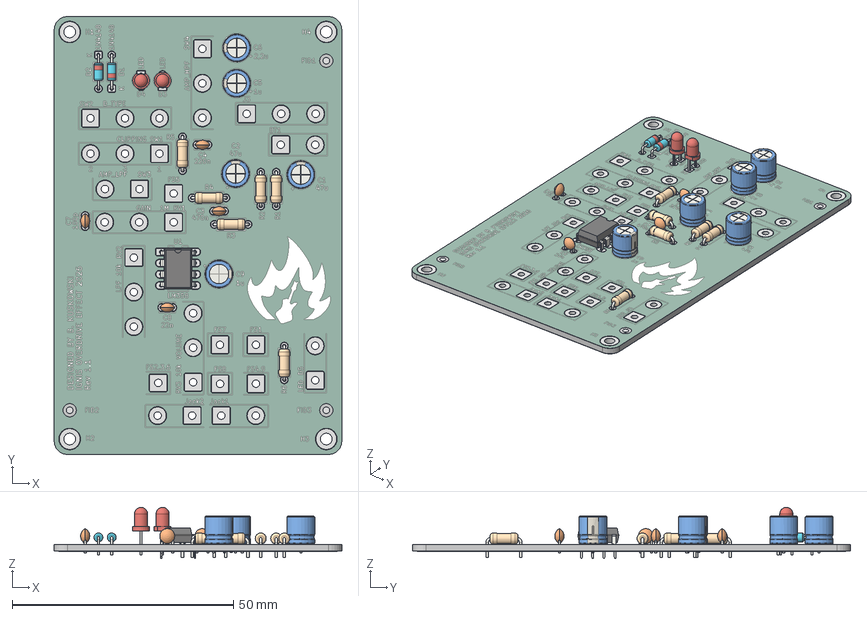
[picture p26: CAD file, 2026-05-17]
model/import/PCB_V1.1.step
65.0 x 99.0 x 11.6 mm
D_DO-35_SOD27_P7.62mm_Horizontal x 2
C_Disc_D3.4mm_W2.1mm_P2.50mm x 4
R_Axial_DIN0207_L6.3mm_D2.5mm_P7.62mm_Horizontal x 6
CP_Radial_D6.3mm_P2.50mm x 5
DIP-8_W7.62mm
LED_D3.0mm x 2
overdrive_effect_copper
overdrive_effect_pad
overdrive_effect_silkscreen
overdrive_effect_soldermask
overdrive_effect_PCB

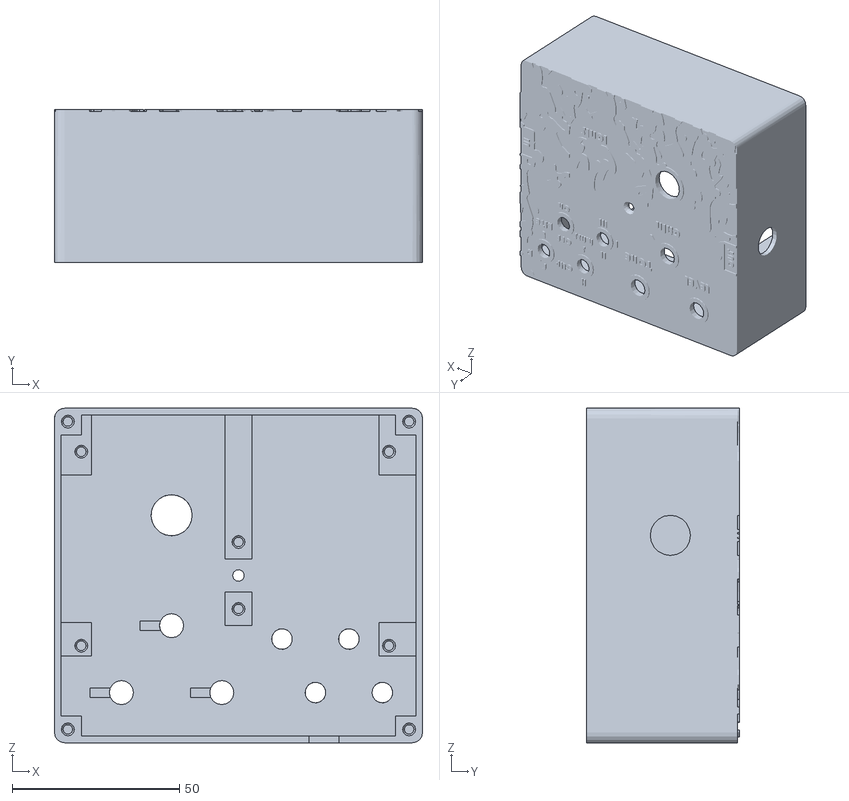
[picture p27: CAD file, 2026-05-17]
model/export/enclosure.stl
110.0 x 45.6 x 100.0

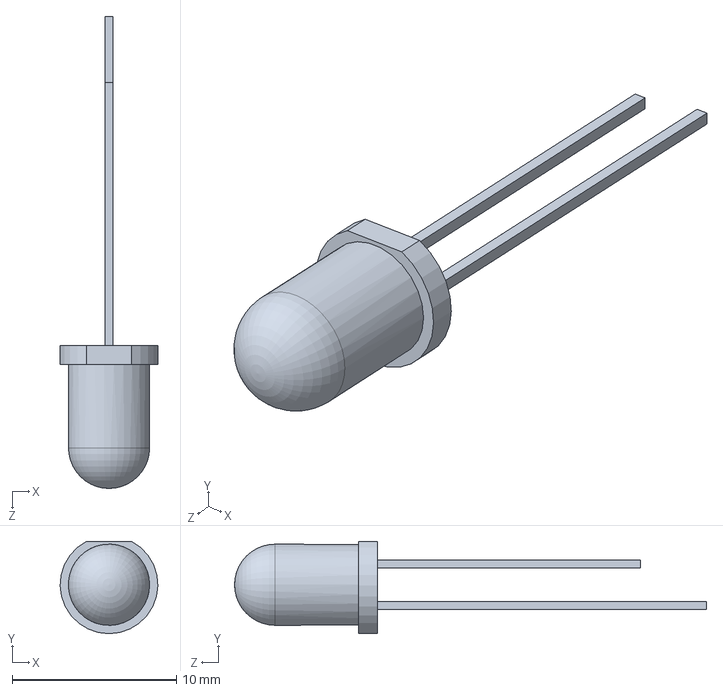
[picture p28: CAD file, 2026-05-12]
model/import/red-led-5mm.SLDPRT
5.95 x 5.62 x 28.7 mm

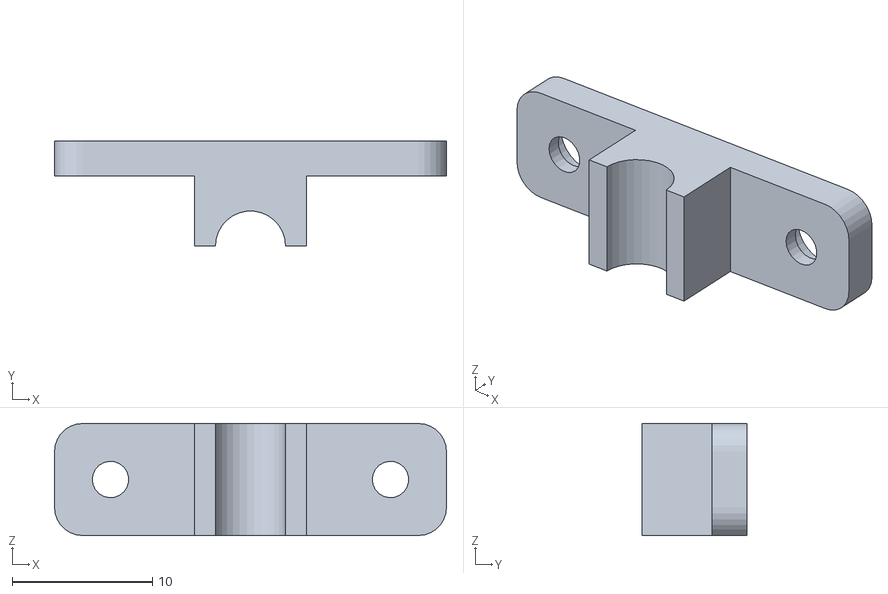
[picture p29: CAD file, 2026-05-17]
model/export/led_holder.stl
28.0 x 7.50 x 8.00

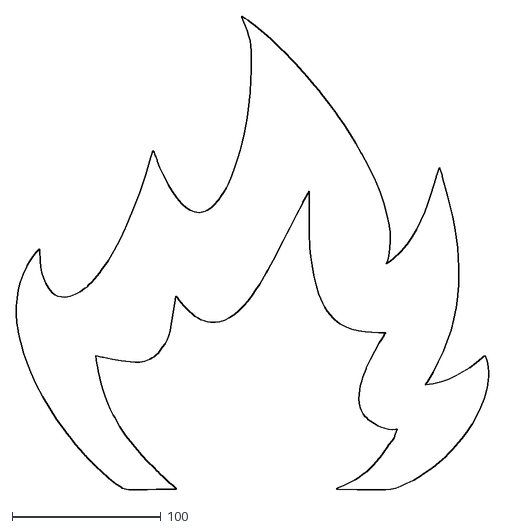
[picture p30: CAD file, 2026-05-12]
model/import/flame.dxf
318.0 x 318.8

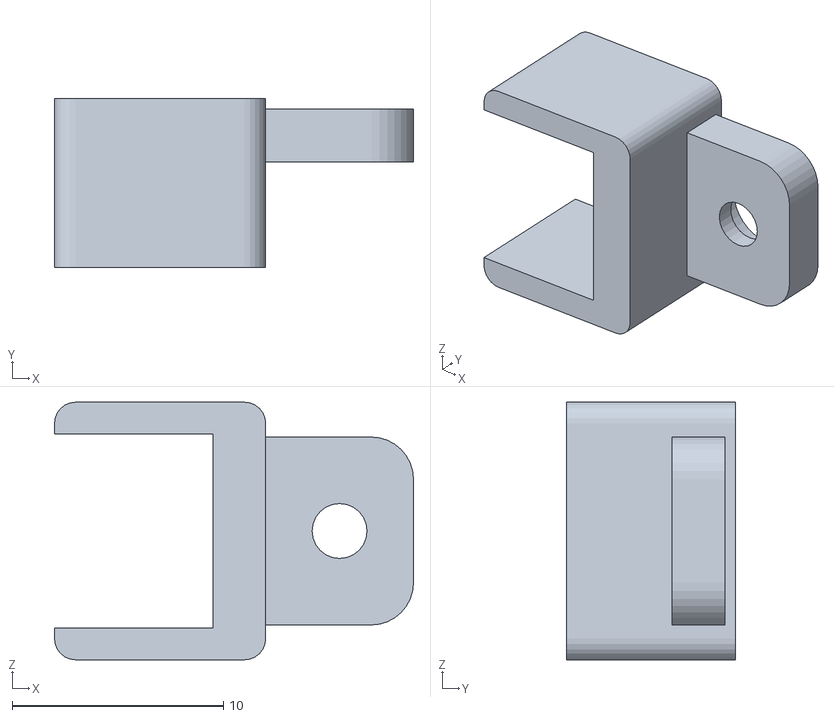
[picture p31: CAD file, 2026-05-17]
model/export/input_holder.stl
17.0 x 8.00 x 12.2

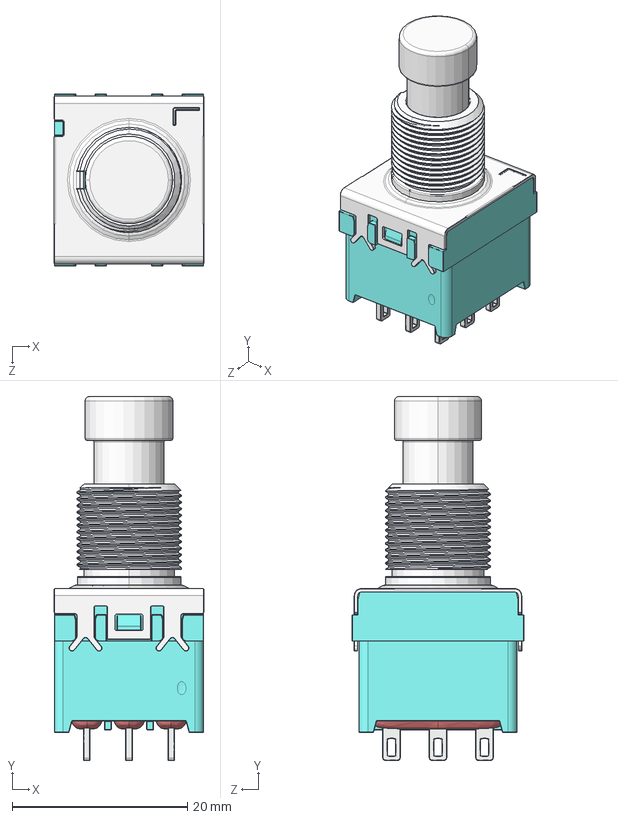
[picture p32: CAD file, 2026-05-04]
model/import/GŘRVA_MECHANO_3PDT_FOOTSWITCH.STEP
17.1 x 41.5 x 19.6 mm

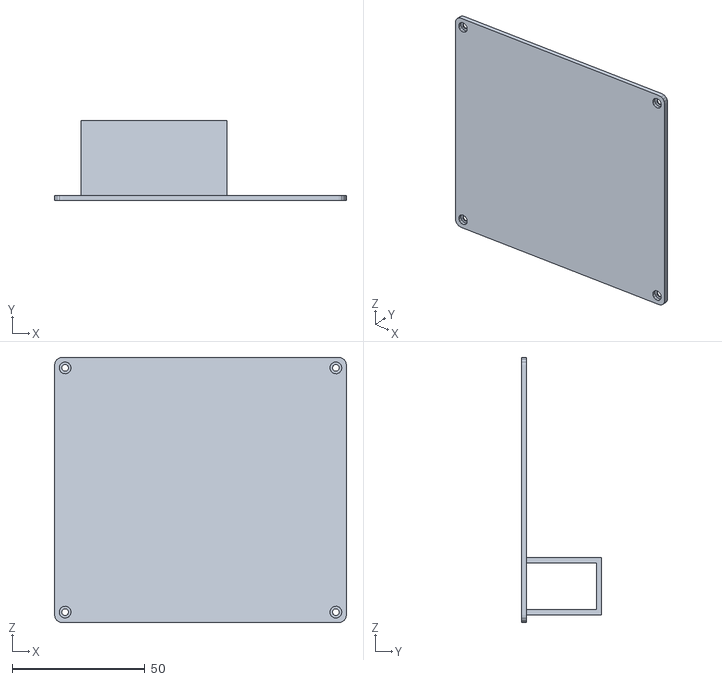
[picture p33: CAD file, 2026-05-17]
model/export/base.stl
110.0 x 30.3 x 100.0

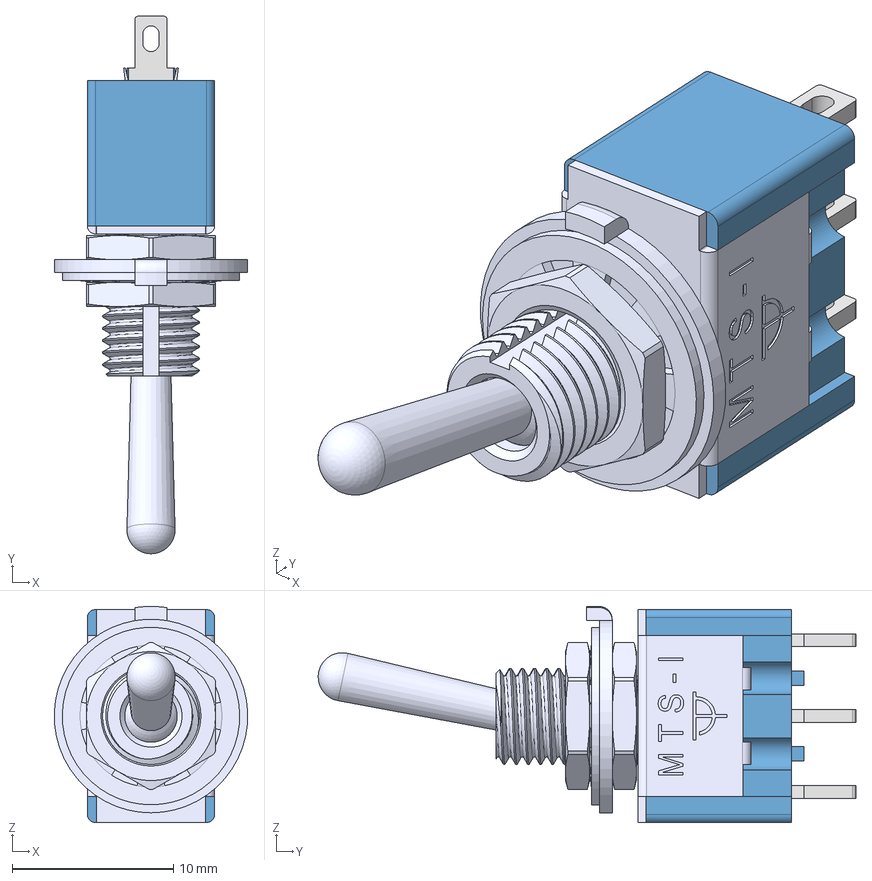
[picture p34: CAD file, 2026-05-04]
model/import/MTS-1xx-A1-blue.step
12.0 x 33.3 x 13.4 mm
Handle
L
Housing

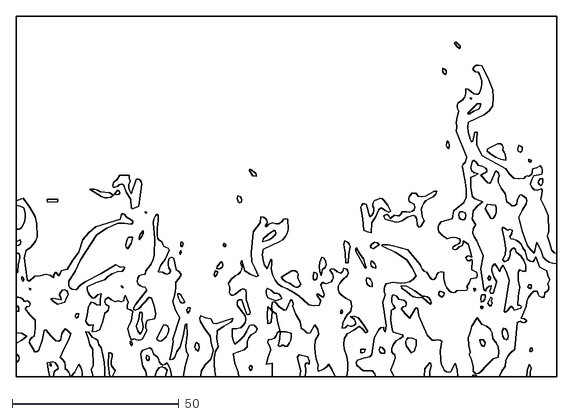
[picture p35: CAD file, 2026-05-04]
model/import/Flames.dxf
161.9 x 107.9

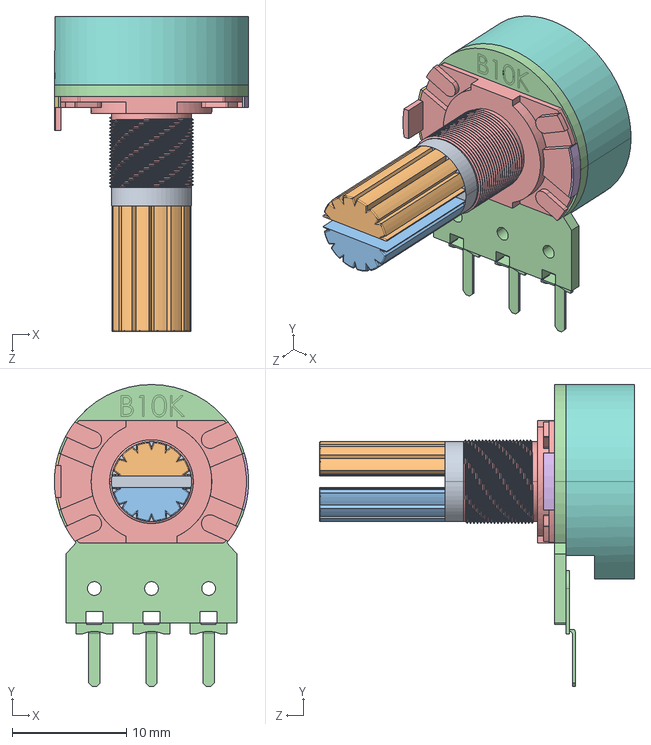
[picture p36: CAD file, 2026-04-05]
model/import/PotentiometerB10K.STEP
17.0 x 26.4 x 27.6 mm

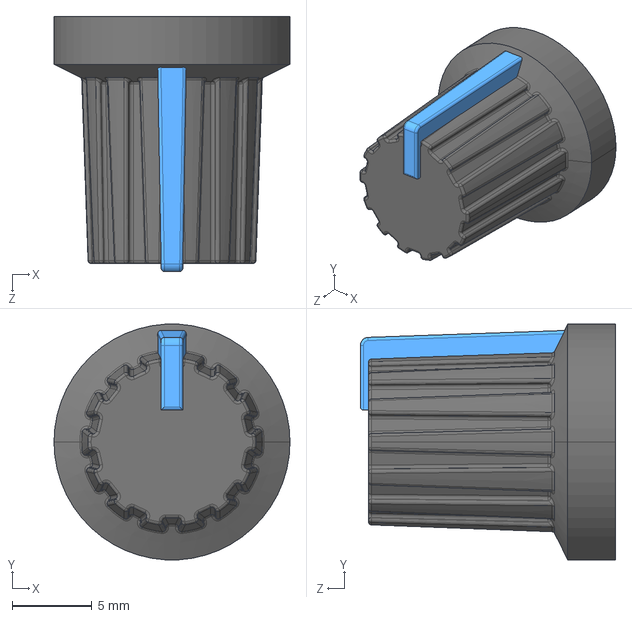
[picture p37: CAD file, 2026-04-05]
model/import/Потенциометр Ручка.STEP
14.8 x 14.8 x 16.0 mm

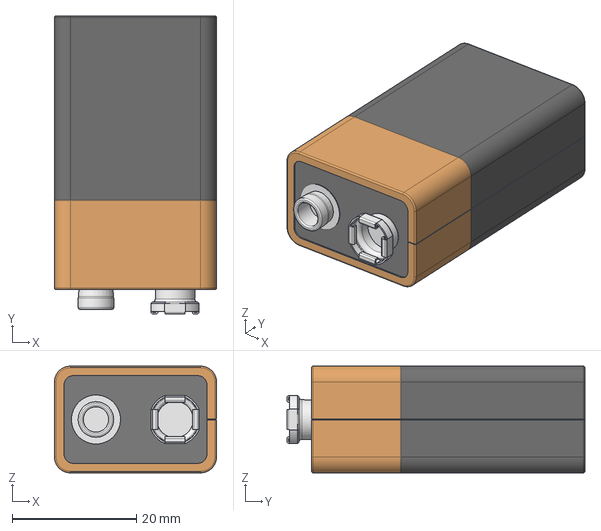
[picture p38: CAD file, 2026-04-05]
model/import/9V-battery.stp
26.0 x 47.9 x 17.1 mm

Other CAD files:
model/import/M12 NUT FOR FOOTSWITCH.STEP
model/import/M7 × 0.75 NUT.STEP
model/import/Push_Button_Nut.STEP
model/9V_battery.ipt
model/9V_input.ipt
model/Jack.ipt
model/Jack_enclosure.ipt
model/Jack_inner.ipt
model/PotentiometerB10K.ipt
model/Push_Button.ipt
model/assembly.iam
model/assembly.ipn
model/base.ipt
model/enclosure.ipt
model/import/GŘRVA_MECHANO_3PDT_FOOTSWITCH/GŘRVA_MECHANO_3PDT_FOOTSWITCH.ipt
model/import/M12 NUT FOR FOOTSWITCH/M12 NUT FOR FOOTSWITCH.ipt
model/import/M7 × 0.75 NUT/M7 × 0.75 NUT.ipt
model/import/MTS-1xx-A1-blue/MTS-1xx-A1-blue-no-nuts.iam
model/import/MTS-1xx-A1-blue/MTS-1xx-A1-blue.iam
model/import/MTS-1xx-A1-blue/MTS-1xx-Base_TH.ipt
model/import/MTS-1xx-A1-blue/MTS-1xx-Contact.ipt
model/import/MTS-1xx-A1-blue/MTS-1xx-Handle.ipt
model/import/MTS-1xx-A1-blue/MTS-1xx-Housing.ipt
model/import/MTS-1xx-A1-blue/MTS-1xx-NUT.ipt
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

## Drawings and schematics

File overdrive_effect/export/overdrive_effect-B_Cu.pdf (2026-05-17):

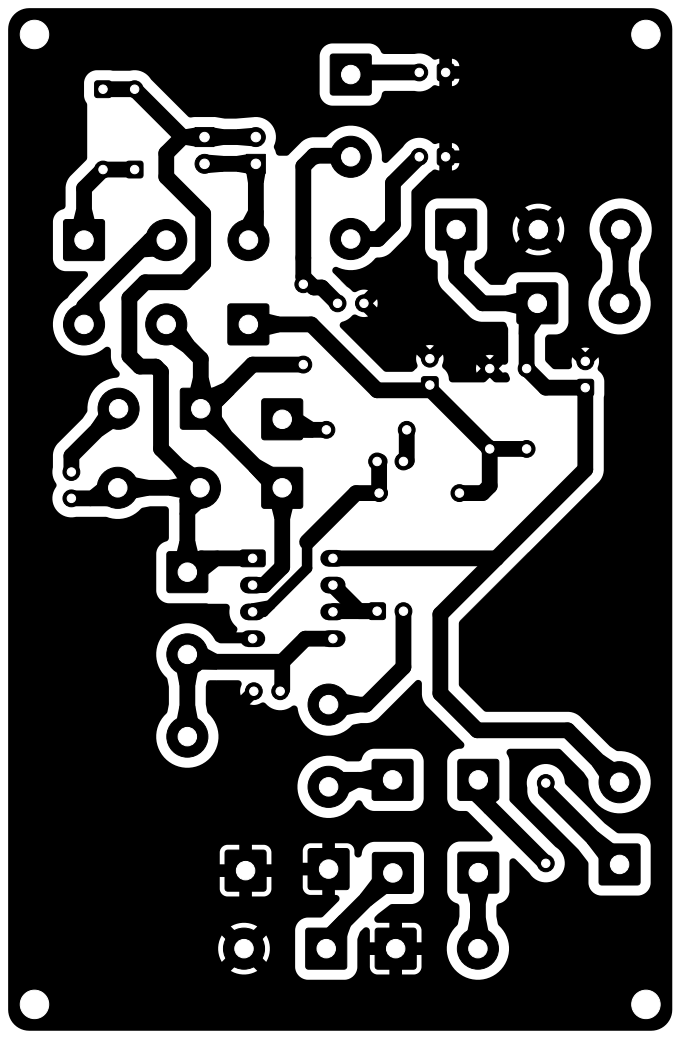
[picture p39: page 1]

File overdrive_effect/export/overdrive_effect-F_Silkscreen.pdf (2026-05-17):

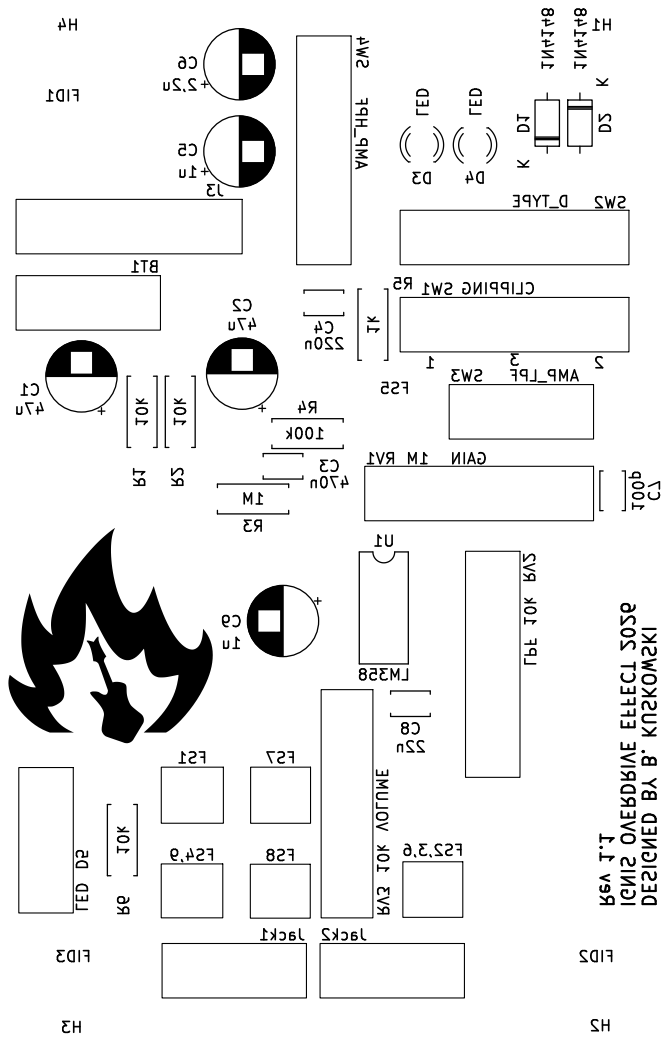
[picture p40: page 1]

2 DESIGNED BY B. KUSKOWSKI IGNIS OVERDRIVE EFFECT 2026 Rev 1.1 CLIPPING

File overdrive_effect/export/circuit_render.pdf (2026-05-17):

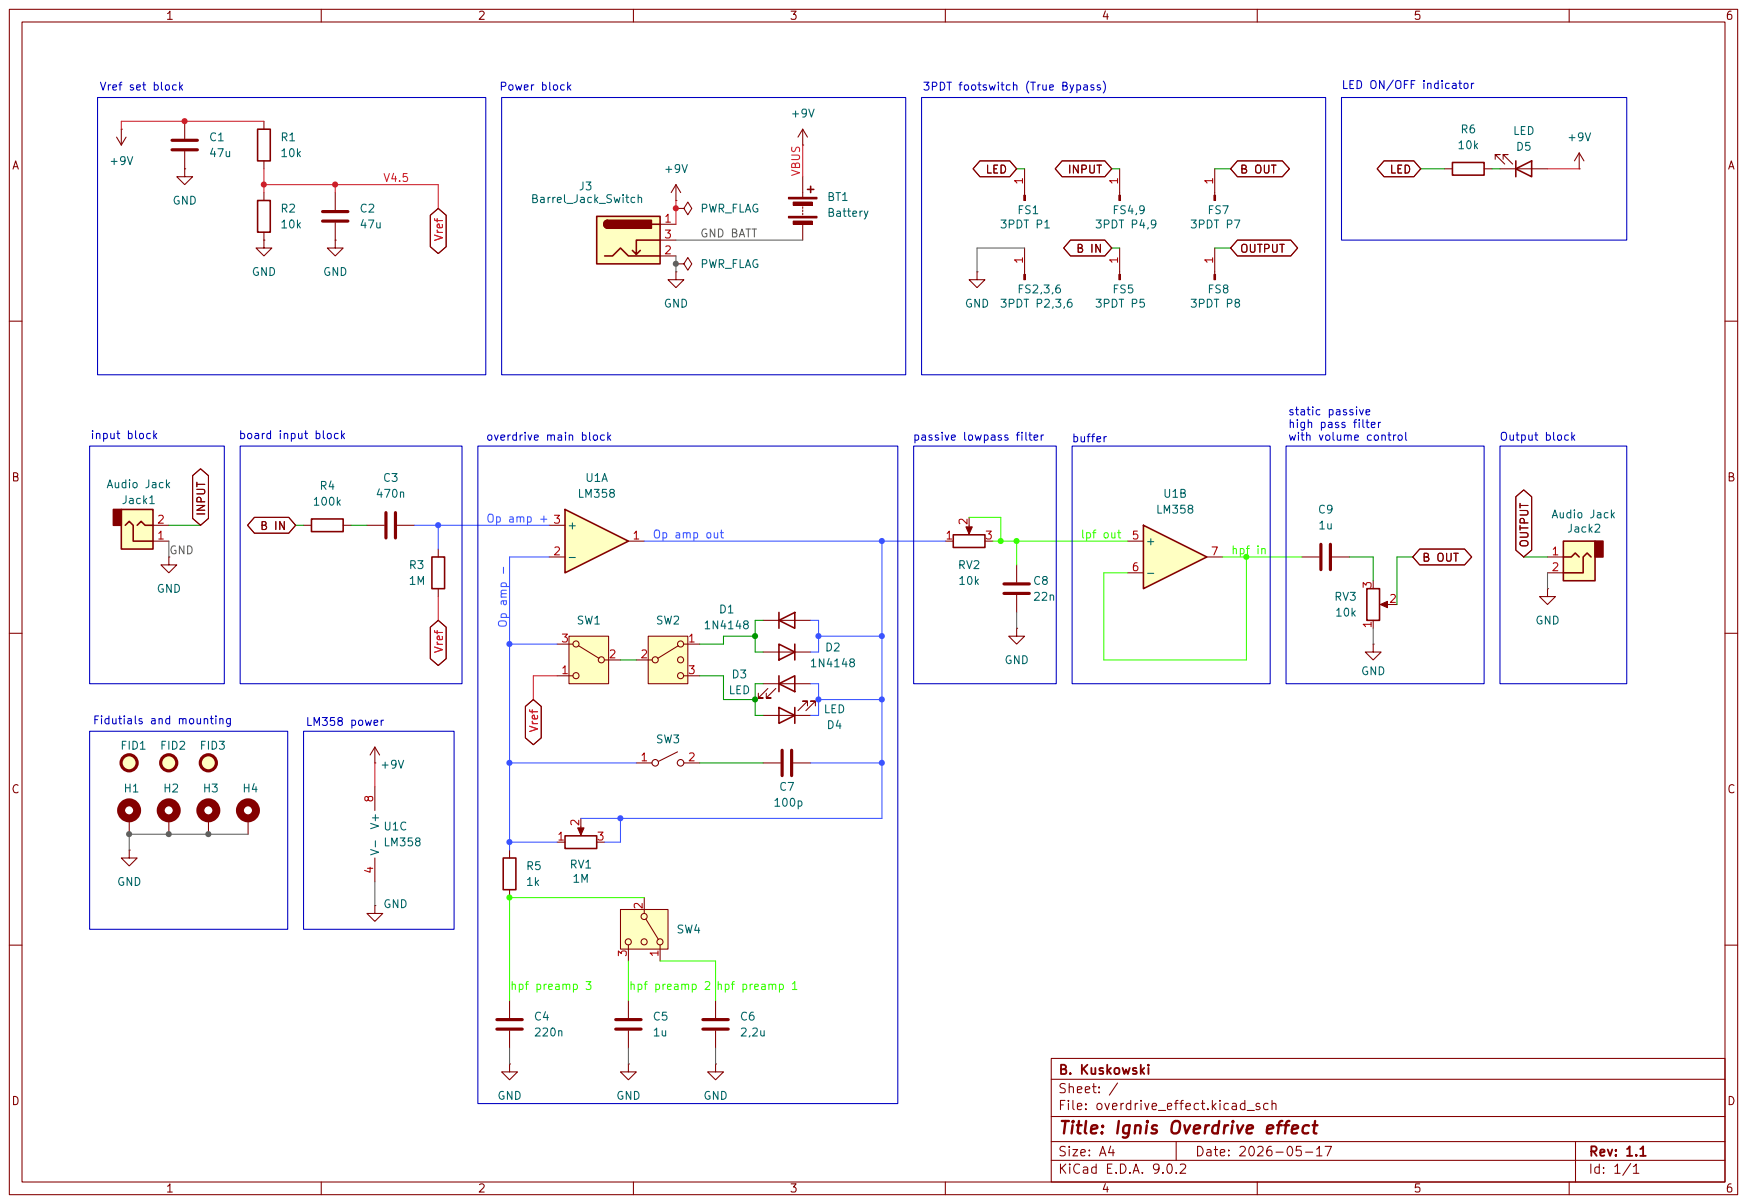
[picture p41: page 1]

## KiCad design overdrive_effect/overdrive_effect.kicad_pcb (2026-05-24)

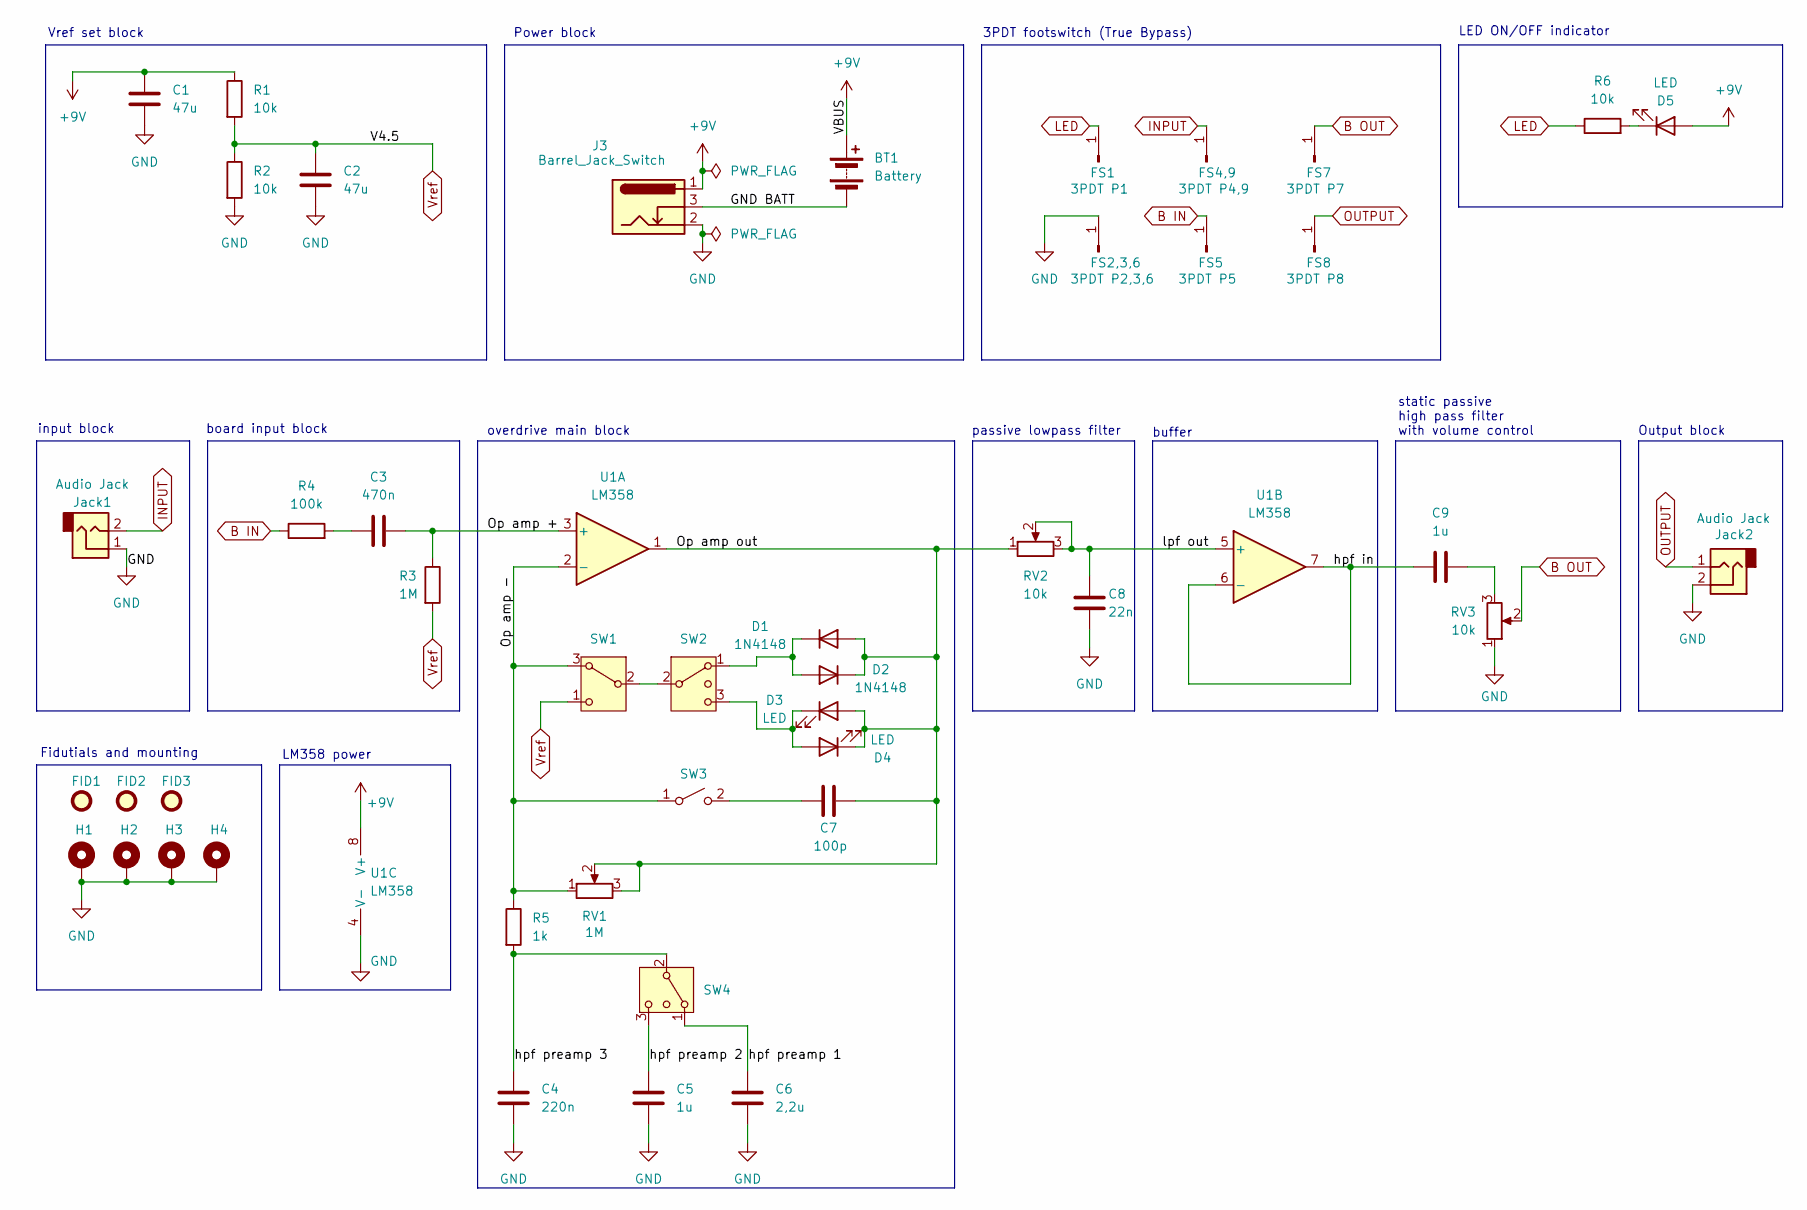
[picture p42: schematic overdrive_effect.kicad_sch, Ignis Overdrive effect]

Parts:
BT1: Battery; SolderWire-1sqmm_1x02_P7.8mm_D1.4mm_OD3.9mm
C1, C2: 47u; CP_Radial_D6.3mm_P2.50mm
C3: 470n; C_Disc_D3.4mm_W2.1mm_P2.50mm
C4: 220n; C_Disc_D3.4mm_W2.1mm_P2.50mm
C5, C9: 1u; CP_Radial_D6.3mm_P2.50mm
C6: 2,2u; CP_Radial_D6.3mm_P2.50mm
C7: 100p; C_Disc_D3.4mm_W2.1mm_P2.50mm
C8: 22n; C_Disc_D3.4mm_W2.1mm_P2.50mm
D1, D2: 1N4148; D_DO-35_SOD27_P7.62mm_Horizontal
D3, D4: LED; LED_D3.0mm
D5: LED; SolderWire-1sqmm_1x02_P7.8mm_D1.4mm_OD3.9mm
FID1, FID2, FID3: Fiducial; Fiducial_1.5mm_Mask3mm
FS1: 3PDT P1; SolderWire-1sqmm_1x01_D1.4mm_OD3.9mm
FS2,3,6: 3PDT P2,3,6; SolderWire-1sqmm_1x01_D1.4mm_OD3.9mm
FS4,9: 3PDT P4,9; SolderWire-1sqmm_1x01_D1.4mm_OD3.9mm
FS5: 3PDT P5; SolderWire-1sqmm_1x01_D1.4mm_OD3.9mm
FS7: 3PDT P7; SolderWire-1sqmm_1x01_D1.4mm_OD3.9mm
FS8: 3PDT P8; SolderWire-1sqmm_1x01_D1.4mm_OD3.9mm
H1, H2, H3, H4: MountingHole_Pad; MountingHole_2.7mm_M2.5_DIN965_Pad
J3: Barrel_Jack_Switch; SolderWire-1sqmm_1x03_P7.8mm_D1.4mm_OD3.9mm
Jack1, Jack2: Audio Jack; SolderWire-1sqmm_1x02_P7.8mm_D1.4mm_OD3.9mm
R1, R2, R6: 10k; R_Axial_DIN0207_L6.3mm_D2.5mm_P7.62mm_Horizontal
R3: 1M; R_Axial_DIN0207_L6.3mm_D2.5mm_P7.62mm_Horizontal
R4: 100k; R_Axial_DIN0207_L6.3mm_D2.5mm_P7.62mm_Horizontal
R5: 1k; R_Axial_DIN0207_L6.3mm_D2.5mm_P7.62mm_Horizontal
RV1: 1M; SolderWire-1sqmm_1x03_P7.8mm_D1.4mm_OD3.9mm
RV2, RV3: 10k; SolderWire-1sqmm_1x03_P7.8mm_D1.4mm_OD3.9mm
SW1: SW_Nidec_CAS-120A1; SolderWire-1sqmm_1x03_P7.8mm_D1.4mm_OD3.9mm
SW2, SW4: SW_SPDT_MSM; SolderWire-1sqmm_1x03_P7.8mm_D1.4mm_OD3.9mm
SW3: SW_SPST; SolderWire-1sqmm_1x02_P7.8mm_D1.4mm_OD3.9mm
U1: LM358; DIP-8_W7.62mm_LongPads

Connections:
+9V: BT1.1 (+), C1.1, D5.2 (A), J3.1, R1.1, U1.8 (V+)
/GND BATT: BT1.2 (-), J3.3
/Op amp +: C3.2, R3.1, U1.3 (+)
/Op amp -: R5.1, RV1.1, SW1.3 (A), SW3.1 (A), U1.2 (-)
/Op amp out: C7.2, D1.2 (A), D2.1 (K), D3.2 (A), D4.1 (K), RV1.2, RV1.3, RV2.1, U1.1
/hpf in: C9.1, U1.6 (-), U1.7
/hpf preamp 1: C6.2, SW4.1
/hpf preamp 2: C5.2, SW4.3 (4)
/hpf preamp 3: C4.2, R5.2, SW4.2 (3)
/lpf out: C8.1, RV2.2, RV2.3, U1.5 (+)
B IN: FS5.1, R4.1
B OUT: FS7.1, RV3.2
GND: C1.2, C2.2, C4.1, C5.1, C6.1, C8.2, FS2,3,6.1, H1.1, H2.1, H3.1, H4.1, J3.2, Jack1.1, Jack2.2, R2.2, RV3.1, U1.4 (V-)
INPUT: FS4,9.1, Jack1.2
LED: FS1.1, R6.1
unnamed: C3.1, R4.2
unnamed: C9.2, RV3.3
unnamed: D1.1 (K), D2.2 (A), SW2.1
unnamed: D3.1 (K), D4.2 (A), SW2.3 (4)
unnamed: D5.1 (K), R6.2
unnamed: SW1.2 (B), SW2.2 (3)
unnamed: C7.1, SW3.2 (B)
OUTPUT: FS8.1, Jack2.1
Vref: C2.1, R1.2, R2.1, R3.2, SW1.1 (C)

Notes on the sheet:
Fidutials and mounting
static passive high pass filter with volume control
LM358 power
overdrive main block
passive lowpass filter
Output block
LED ON/OFF indicator
input block
Power block
3PDT footswitch (True Bypass)
Vref set block
board input block
buffer

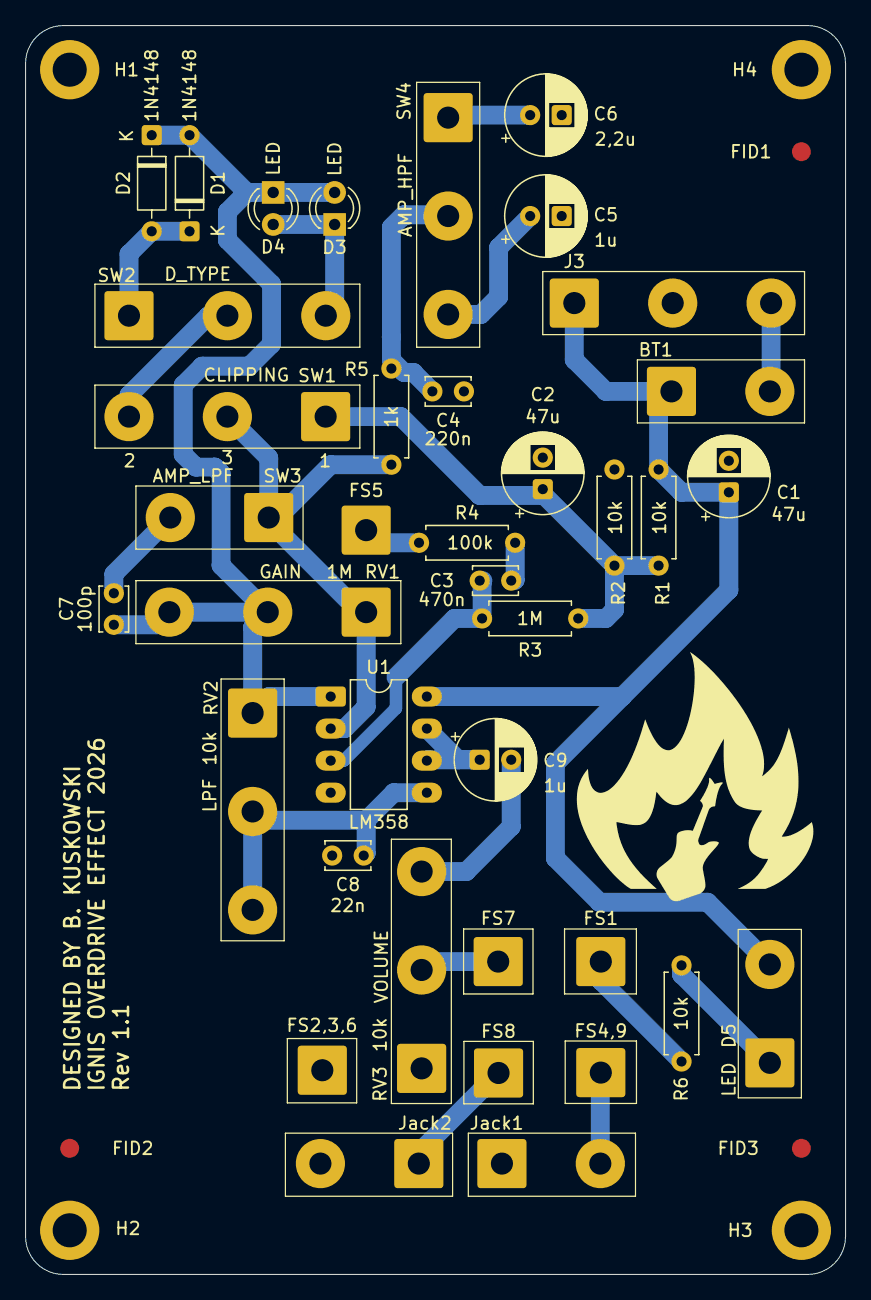
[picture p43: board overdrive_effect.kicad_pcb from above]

Board: 2 copper layers, 65.0 x 99.0 mm, 45 parts (0 on the bottom side), 24 nets.

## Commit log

2026-04-06 README update #1
    [overdrive_effect.kicad_pcb, overdrive_effect.kicad_sch]
2026-04-13 kicad project added
    [overdrive_effect.kicad_sch, zlozenie.0024.iam, zlozenie.0025.iam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]
2026-04-20 README update #2 and electrical schematic update
    [Po_optymalizacji.ipt, overdrive_effect.kicad_sch]
2026-04-25 KiCAD blueprint development
    [overdrive_effect.kicad_pcb, overdrive_effect.kicad_sch]
2026-04-26 KiCAD traces
    [overdrive_effect.kicad_pcb]
2026-04-26 Cleanup 2
    [9V-battery.stp, 9V_battery.ipt, 9V_input.ipt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]
2026-05-04 Model update
    [9V_input.ipt, CP_Radial_D6.3mm_P2.50mm.ipt, C_Disc_D3.4mm_W2.1mm_P2.50mm.ipt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]
2026-05-12 Model development/PCB pdfs
    [9V_input.ipt, assembly.iam, base.ipt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]
2026-05-15 Rev 1.0
    [9V_input.ipt, assembly.iam, base.ipt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]
2026-05-15 Next revision fixed board
    [overdrive_effect.kicad_pcb, overdrive_effect.kicad_sch]
2026-05-17 new renders, 3mf setup
    [CP_Radial_D6.3mm_P2.50mm.ipt, C_Disc_D3.4mm_W2.1mm_P2.50mm.ipt, DIP-8_W7.62mm.ipt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]
2026-05-17 KiCad circuit renders
    [overdrive_effect.kicad_sch]
2026-05-17 Blick diagram explanation
    [overdrive_effect.kicad_pcb]
2026-05-17 PCB Layers exported
    [overdrive_effect.kicad_pcb]
2026-05-18 BOM & Mechanical added to docs
    [BOM.xlsx, assembly.iam, base.ipt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]
2026-05-18 BOM update & assembly notes
    [BOM.xlsx]
2026-05-24 Gerbers added
    [overdrive_effect.kicad_pcb]
